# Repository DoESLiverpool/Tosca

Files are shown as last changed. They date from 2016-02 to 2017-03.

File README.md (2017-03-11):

# Code now at: https://bitbucket.org/goatchurch/bbhquad
# Instructions are at: https://github.com/DoESLiverpool/wiki/wiki/PolarGraph
# Issues still here for the moment

## Tosca

Machinekit-powered polargraph drawing robot.

As part of the [Phrased & Confused](http://www.phrasedandconfused.co.uk/) at [Liverpool Acoustic Festival](http://www.phrasedandconfused.co.uk/events/phrased-confused-at-liverpool-acoustic-festival-3) we're aiming to have a polargraph perform alongside a poet.

## Reference Links

 * [Machinekit](http://www.machinekit.io/) - the operating system to control the CNC motors.
 * [Gcode generation](https://github.com/DoESLiverpool/Tosca/blob/master/GcodeFiles.md)

## Name

Named after the mother of Knut, the famous *polar* bear from Berlin Zoo.

## Updates

System now does not use machinekit and is now able to run PWM-H-bridge servos and quadrature decodes directly from the board.

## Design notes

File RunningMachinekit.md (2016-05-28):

# Getting Machinekit Running

This assumes you've already got a Beaglebone with Machinekit installed, but can be expanded as we get more detail on installing things.  It also assumes you have a computer running Linux to connect it to.

## Starting Machinekit
1. Plug the Beaglebone into the laptop with a USB cable
1. Connect to the Beaglebone
  ```
  ssh -X machinekit@192.168.7.2 
  ```

  > If this doesn't work, then plug the Beaglebone onto the network with an Ethernet cable, and find its IP address via other means.  The Beaglebone only sets up the Ethernet on boot though, so you'll need to reboot it to fix that.

1. Connect through the network to the BB by running:  nmap -p22 192.168.0.255/24 and look for something that is open to get the ipnumber  (this should be fixed by https://github.com/DoESLiverpool/Tosca/issues/27 )
1. Log in machinekit@192.168.0.130 with the password machinekit over the network (or 192.168.7.2 if over the USB ssh over serial)
1. Run the machinekit software.  This will spawn a new window on your laptop, which is actually running on the Beaglebone and just using your laptop as a display.
  ```
  cd machinekit
  
  . scripts/rip-environment
  
  machinekit mk7_bbb_pcb.ini
  ```
1. Home the machine by using left right up down cursor keys to put the pen in the middle of the board with both strings at right angles to each other.  Click on "home all"
1. Type in the following Gcode command to set the current position to home.
  ```
  g92x0y0
  ```

## Drawing something

1. Load a Gcode file, with "File" -> "Open"
1. For example, go up one directory and load bighelloworld.ngc
1. [Optional] Manually jog to a starting point and set it as home with
  ```
  g92x0y0
  ```
1. Control the speed with manual Feed override and max velocity (for the "retracted" linking moves) 
1. Click the play icon.

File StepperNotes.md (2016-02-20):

# Stepper Version Notes

Notes on the version using the TLRN steppers.

For instructions on how to use the software to drive it, see [RunningMachinekit](RunningMachinekit.md) as the instructions are the same for both Polargraphs.

They have [BigEasyDriver boards](http://SchmalzHaus.com/BigEasyDriver) to run the steppers.  On the existing wiring, the colour coding is as follows:
 * White - direction
 * Blue - step
 * Green - sleep
 * Red - Vcc
 * Black - Ground

Pin mapping is in the .hal file.

If you ground pin P9-11, that disables the e-stop.

You can see the signals if you do machine -> show hal configuration

On the Beaglebone the pin-outs are as follows:
https://graycat.io/wp-content/uploads/2012/12/beaglebone_pinout.png

according to mk7_bbb_pcb.hal:
 * P9-11 - estop connect to Ground
 * P9-13 - limit switch connect to Ground 6 times during the homing cycle (before you can load an G-code)
 * P9-15 - probe-in (connect to ground to show it light up)
  
 * P9-29 - step (axis 0)
 * P9-31 - direction (axis 0)
 * P9-28 - direction (axis 1)
 * P9-30 - step (axis 1)

FIXME might be able to hack the HAL (/ini) to change speed, etc. for the homing and simplify that

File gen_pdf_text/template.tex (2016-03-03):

\documentclass[$if(fontsize)$$fontsize$,$endif$$if(handout)$handout,$endif$$if(beamer)$ignorenonframetext,$endif$$for(classoption)$$classoption$$sep$,$endfor$]{$documentclass$}
$if(theme)$
\usetheme{$theme$}
$endif$
$if(colortheme)$
\usecolortheme{$colortheme$}
$endif$
$if(fonttheme)$
\usefonttheme{$fonttheme$}
$endif$
\usepackage{amssymb,amsmath}
\usepackage{ifxetex,ifluatex}
\usepackage{fixltx2e} % provides \textsubscript
\ifxetex
  \usepackage{fontspec,xltxtra,xunicode}
  \defaultfontfeatures{Mapping=tex-text,Scale=MatchLowercase}
\else
  \ifluatex
    \usepackage{fontspec}
    \defaultfontfeatures{Mapping=tex-text,Scale=MatchLowercase}
  \else
    \usepackage[utf8]{inputenc}
  \fi
\fi
$if(natbib)$
\usepackage{natbib}
\bibliographystyle{plainnat}
$endif$
$if(biblatex)$
\usepackage{biblatex}
$if(biblio-files)$
\bibliography{$biblio-files$}
$endif$
$endif$
$if(listings)$
\usepackage{listings}
$endif$
$if(lhs)$
\lstnewenvironment{code}{\lstset{language=Haskell,basicstyle=\small\ttfamily}}{}
$endif$
$if(highlighting-macros)$
$highlighting-macros$
$endif$
$if(verbatim-in-note)$
\usepackage{fancyvrb}
$endif$
$if(tables)$
\usepackage{longtable}
% These lines are needed to make table captions work with longtable:
\makeatletter
\def\fnum@table{\tablename~\thetable}
\makeatother
$endif$
$if(url)$
\usepackage{url}
$endif$
$if(graphics)$
\usepackage{graphicx}
% Redefine \includegraphics so that, unless explicit options are
% given, the image width will not exceed the width of the page.
% Images get their normal width if they fit onto the page, but
% are scaled down if they would overflow the margins.
\makeatletter
\def\ScaleIfNeeded{%
  \ifdim\Gin@nat@width>\linewidth
    \linewidth
  \else
    \Gin@nat@width
  \fi
}
\makeatother
\let\Oldincludegraphics\includegraphics
\renewcommand{\includegraphics}[2][]{\Oldincludegraphics[width=\ScaleIfNeeded]{#2}}
$endif$

%gets rid of bottom navigation bars
\setbeamertemplate{footline}[frame number]{}

%gets rid of bottom navigation symbols
\setbeamertemplate{navigation symbols}{}

%gets rid of footer
%will override 'frame number' instruction above
%comment out to revert to previous/default definitions
\setbeamertemplate{footline}{}

% Comment these out if you don't want a slide with just the
% part/section/subsection/subsubsection title:
\AtBeginPart{
  \let\insertpartnumber\relax
  \let\partname\relax
  \frame{\partpage}
}
\AtBeginSection{
  \let\insertsectionnumber\relax
  \let\sectionname\relax
  \frame{\sectionpage}
}
\AtBeginSubsection{
  \let\insertsubsectionnumber\relax
  \let\subsectionname\relax
  \frame{\subsectionpage}
}

$if(strikeout)$
\usepackage[normalem]{ulem}
% avoid problems with \sout in headers with hyperref:
\pdfstringdefDisableCommands{\renewcommand{\sout}{}}
$endif$
\setlength{\parindent}{0pt}
\setlength{\parskip}{6pt plus 2pt minus 1pt}
\setlength{\emergencystretch}{3em}  % prevent overfull lines
$if(numbersections)$
$else$
\setcounter{secnumdepth}{0}
$endif$
$if(verbatim-in-note)$
\VerbatimFootnotes % allows verbatim text in footnotes
$endif$
$if(lang)$
\usepackage[$lang$]{babel}
$endif$
$for(header-includes)$
$header-includes$
$endfor$

$if(title)$
\title{$title$}
$endif$
$if(subtitle)$
\subtitle{$subtitle$}
$endif$
$if(author)$
\author{$for(author)$$author$$sep$ \and $endfor$}
$endif$
$if(date)$
\date{$date$}
$endif$

\begin{document}
$if(title)$
\frame{\titlepage}
$endif$

$for(include-before)$
$include-before$

$endfor$
$if(toc)$
\begin{frame}
\tableofcontents[hideallsubsections]
\end{frame}

$endif$
$body$

$if(natbib)$
$if(biblio-files)$
$if(biblio-title)$
$if(book-class)$
\renewcommand\bibname{$biblio-title$}
$else$
\renewcommand\refname{$biblio-title$}
$endif$
$endif$
\begin{frame}[allowframebreaks]{$biblio-title$}
\bibliography{$biblio-files$}
\end{frame}

$endif$
$endif$
$if(biblatex)$
\begin{frame}[allowframebreaks]{$biblio-title$}
\printbibliography[heading=none]
\end{frame}

$endif$
$for(include-after)$
$include-after$

$endfor$
\end{document}

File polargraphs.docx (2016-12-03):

Sandy Noble original polargraph

http://www.polargraph.co.uk – lots of stuff

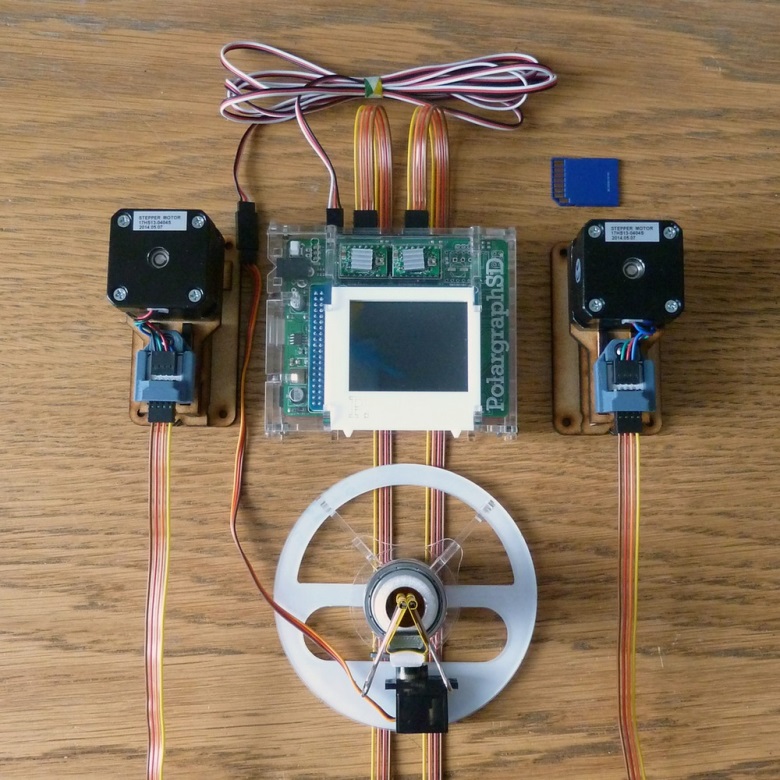
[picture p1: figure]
Image of PolargraphSD v2.0 - Complete, tested
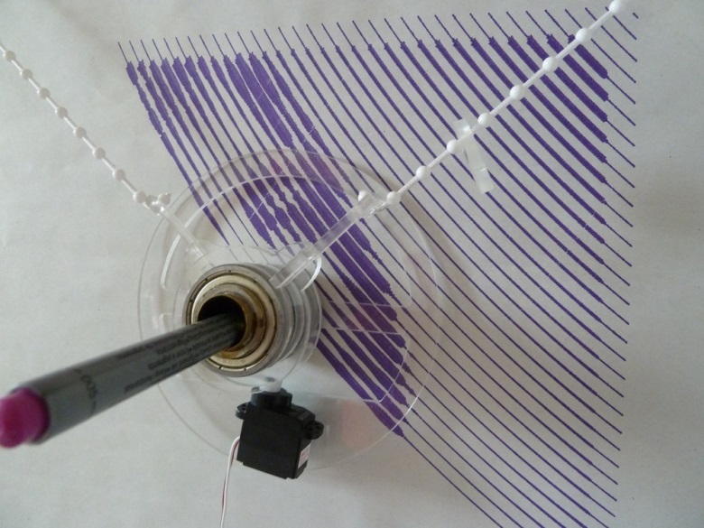
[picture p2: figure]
Image of PolargraphSD v2.0 - Complete, tested

http://www.instructables.com/id/Polargraph-Drawing-Machine/

https://github.com/euphy/polargraphcontroller/releases/tag/2016-03-29-10-23

Makelangelo

http://www.makelangelo.com/ Buy from https://www.marginallyclever.com/product/makelangelo-2-5-2/

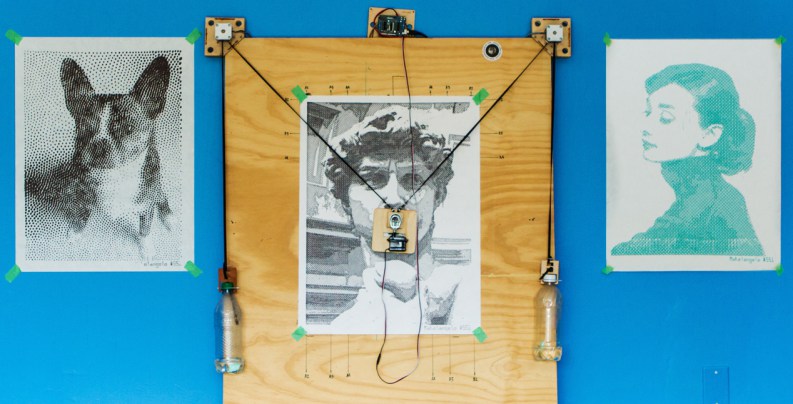
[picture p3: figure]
The Makelangelo 2.5

https://www.marginallyclever.com/product/makelangelo-software/

Mark Benson - Make Bournemouth

https://www.makebournemouth.com/?tag=polargraph

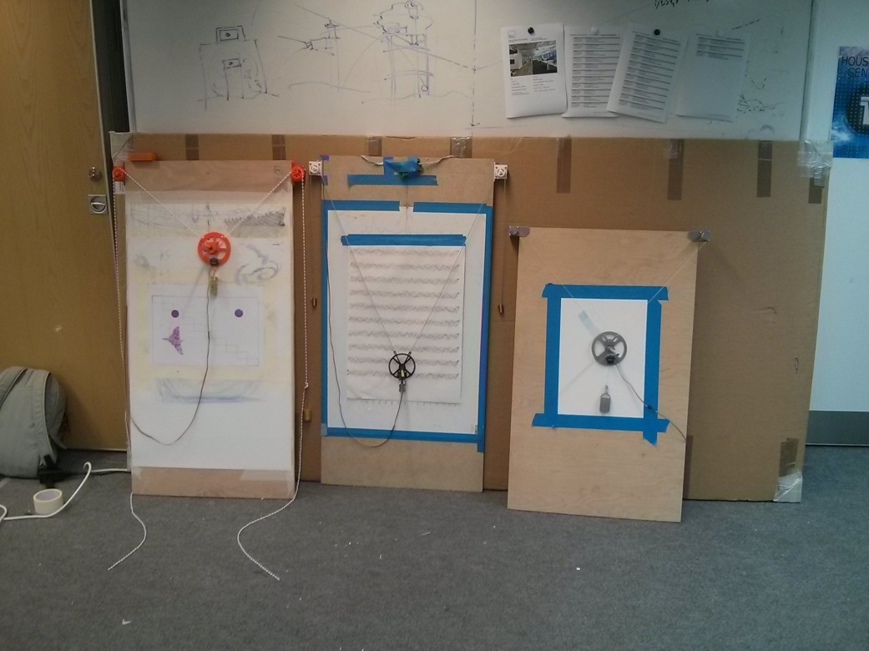
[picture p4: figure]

“The one on the left is running the Gocupi (https://github.com/brandonagr/gocupi) firmware and is being run with Pycupi (https://github.com/brianinnes/pycupi) a Python port/rewrite of the Gocupi ‘Go (https://golang.org/)‘ control software.

The other two are running the Polargraph.co.uk a1_server firmware variant modified to run on our (https://github.com/MarkJB/polargraph_server_a1) electronics (https://github.com/MarkJB/Eggbot-Spherebot-Polargraph-Controller).

The one in the middle is running with Pylargraph (https://github.com/MarkJB/pylargraph) which is a Python script to control the original firmware with the intention of plotting or graphing the result of a regular twitter search.

The other is running with the Polargraph.co.uk control software.

The various 3d printed parts are our own designs or modified versions of existing designs.

My own designs are available on github (https://github.com/MarkJB/Polargraph-printed-parts) and thingiverse (http://www.thingiverse.com/MarkBenson/collections/polargraph) but not everything is finished.”

https://github.com/MarkJB/Polargraph-printed-parts

http://www.thingiverse.com/MarkBenson/collections/v-plotter-polargraph-stuff

We’ve had a go at the gondola , which appears small and fragile – we think that the disc touching the drawing surface improved stability

Experimented with another disc further from the drawing surface to move the centre of gravity back

https://www.makebournemouth.com/?p=831 Pycupi v-plotter control software

Alex Weber – Der Kritzler– Designed for writing on windows!

https://tinkerlog.com/2011/09/02/der-kritzler/

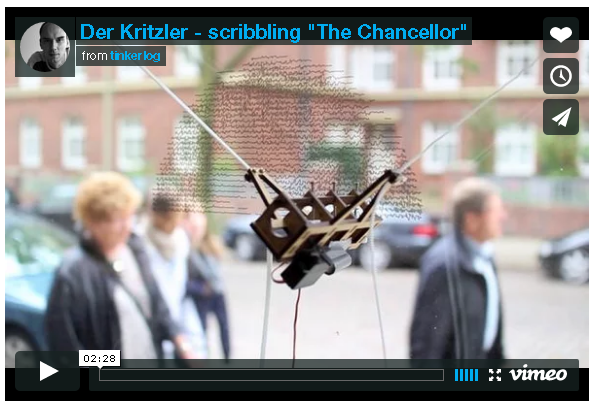
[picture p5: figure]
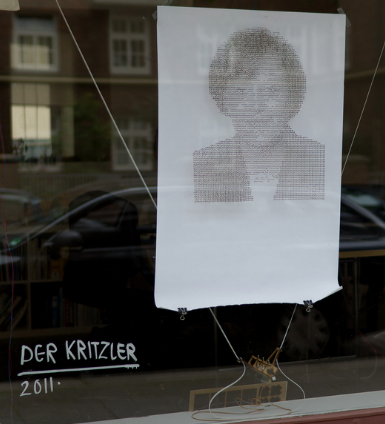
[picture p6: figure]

https://github.com/tinkerlog/Kritzler

Jacob Gertsch – LinuxCNC Bipod Plotter

https://www.youtube.com/user/ArduinoBeam

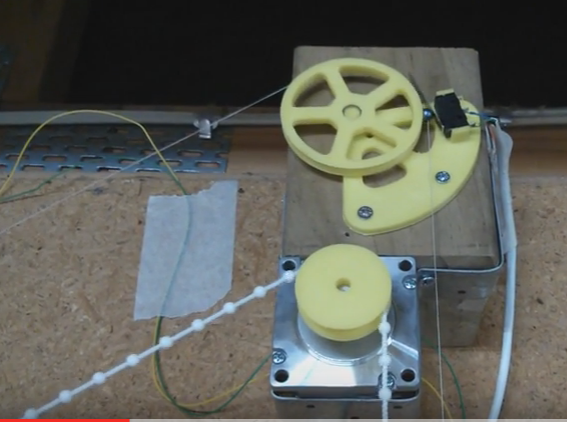
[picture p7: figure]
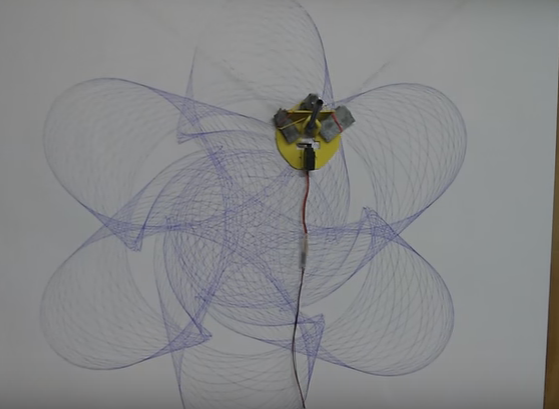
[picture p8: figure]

https://github.com/Chojins/LinuxCNC-Polargraph (mainly using Solidworks)

https://github.com/Chojins/Guilloche-Designer (spirograph-type designs)

Jakob Flierl - Koppi’s Toy (uses a toothed belt)

http://wiki.linuxcnc.org/cgi-bin/wiki.pl?Koppi%27s_Toy

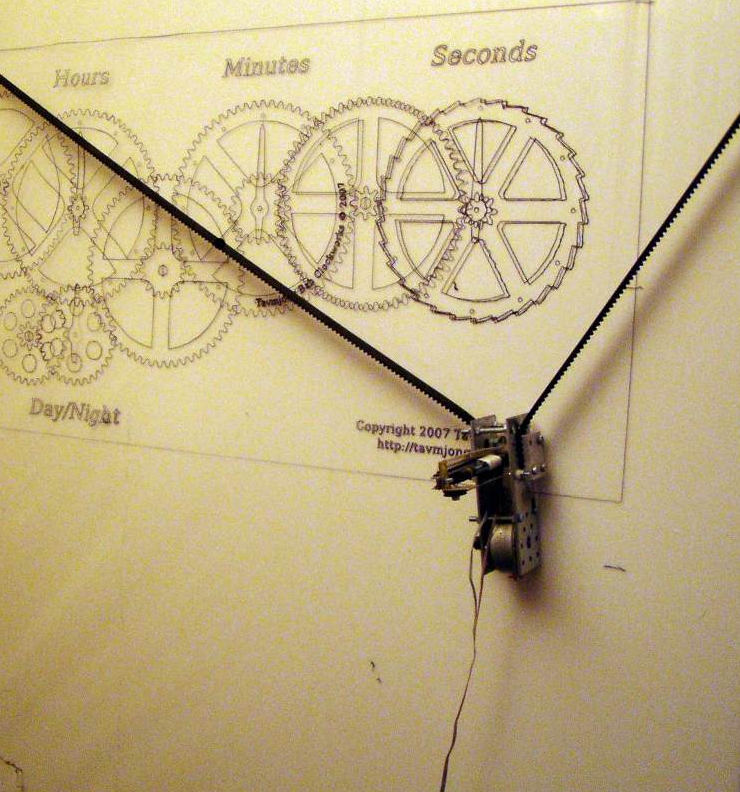
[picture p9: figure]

Matt Venn

http://www.mattvenn.net/2011/09/19/polargraph-energy-monitoring/

http://www.mattvenn.net/2015/12/19/megadrawbz/

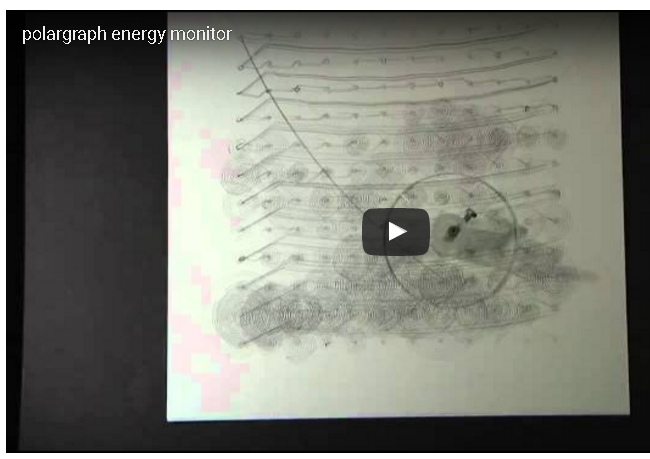
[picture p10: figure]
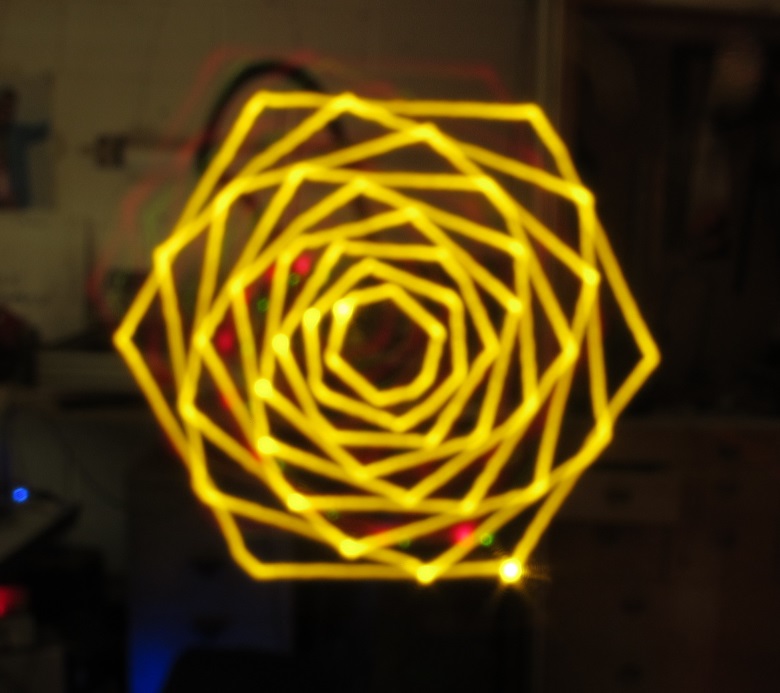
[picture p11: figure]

Brandon Dunson / Brandon Green - Gocupi Raspberry pi polargraph

https://github.com/brandonagr/gocupi

https://www.kickstarter.com/projects/1412673920/gocupi-turns-your-raspberry-pi-into-a-portable-pol

http://www.geeky-gadgets.com/transform-your-raspberry-pi-into-a-portable-polargraph-with-gocupi-05-08-2014/

https://blog.adafruit.com/2012/11/23/gocupi-go-raspberry-pi-polargraph-piday-raspberrypi-raspberry_pi/

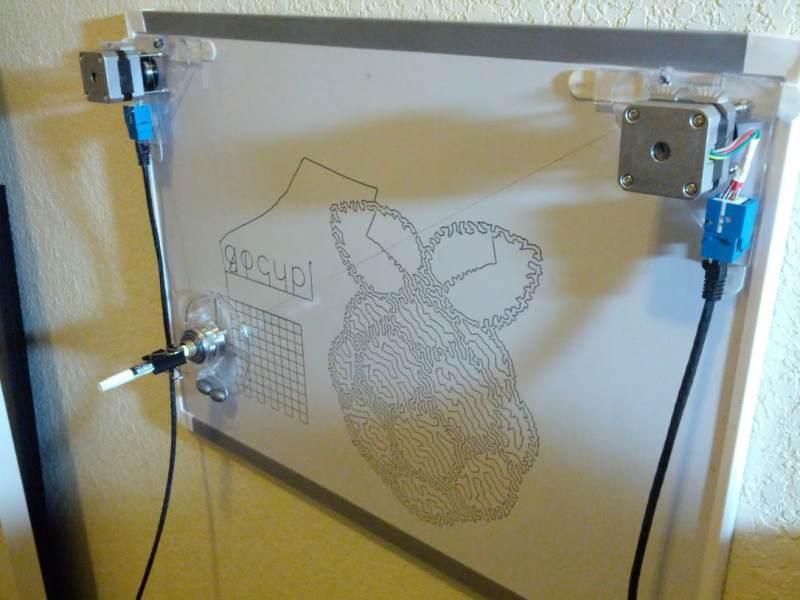
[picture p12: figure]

“This project is different from most other Polargraphs in that there is no step generation code on the arduino, everything is calculated in Go and then the arduino just receives a stream of step deltas that it stores in a memory buffer and then executes. Since all logic is written in Go running on the Pi it allows using more advanced interpolation models for smooth drawing, not needing to use fixed point or single precision floats for calculations, not needing to reflash the arduino often when making code changes, etc.”

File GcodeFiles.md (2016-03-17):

# Generating G-code files

Either fight it out with Inkscape, or use:
**http://doesliverpool.github.io/svgraph.html**

## Resizing for the playing area instructions
1. The width needs to be put into the machinekit/tosca.hal file (find it and change it on the BB)
1. Home point origin (where you start from) is width\*0.5 down from the top left pulley, and then across by width\*0.5
1. Edit twistcodewiki/cgipipe/xylimits

## Poetry instructions
1. Log on to BB, go into "twistcodewiki" directory and run the script "pytwister".  This makes a webserver that listens on port 9003.
1. SSH Log on to BB again in another window, but with -X setting: cd machinekit \n . scripts/rip-environment \n machinekit tosca.ini
1. This calls up the axisUI controlling the maching.  Move to home position, click [home], load /home/machinekit/poetrygcode.ngc
1. Go to http://doesliverpool.github.io/svgraph.html, fill in the IP number into the box, hit return and it goes green
1. Type your poetry into "svgizing letters here" box, click [svgizetext].  This will relay the poetry directly to the BB which will gcode it in space available
1. Click "reload" icon on axisUI and now click on run icon
1. Last 3 steps will happen from a POST command to http://192.168.7.2:9003/cgipipe/genpoetry.py?centre=no' where the POST data is the ascii text of the poem with '\n' linefeeds.
1. This enables the 3-click poem of "export from Csharp", "reload in axisUI", "run in axisUI"

## Toxteth map instructions
1. SSH log on to BB with -X setting. and boot up axisUI
1. The files to plot will be in ../performancegcodes/*.ngc numbered in order
1. I will help lay out the map and the icons onto the map (position and scaling) using svgraph.html technology on Friday morning

## Basic Instructions

1. Works best in CHROME browser.
1. Drag and drop your SVG file onto the screen **FIRST**.  This sets the scale.
1. (Alternatively to go from text, click on [svgize text] to make file from text box)
1. Use middle mouse scrollwheel to ZOOM on cursor.  There is no drag view!
1. Click on [MKstats] button to get the background drawing shape
1. Use Left Mouse Button to drag SVG data against the view, or Ctrl-Left Mouse to spin the shape (these features were designed for nesting)
1. Click [Save G-code] button to download fresh and thinned G-code, which you will then have to copy to the Beaglebone using scp

## Connected instructions

It's possible to get the G-code file to upload directly to the BB.

1. Log on to BB, go into "twistcodewiki" directory and run the script "pytwister".  This makes a webserver that listens on port 9003.
1. On the "svgraph.html" webpage, fill in the IPnumber for the BB and hit return.  If it works, this box will go green.  
1. The [MKstats] button will read the dimensions and status of the BB (in particular if it's running the Machinekit/Axis X-window application.
1. The [Send G-code] button will automatically upload and save g-code to a file called "/home/machinekit/gcodetwisted.ngc"
1. If the tickbox to the right is set, then it will attempt to autorun the g-code when it is uploaded.   (In the unlikely event this works, it won't redraw the picture on the Machinekit/Axis X-window

The webserver thing running on BB that holds the scripts is at https://bitbucket.org/goatchurch/twistcodewiki
Someone could replace it with a simple flask framework or something

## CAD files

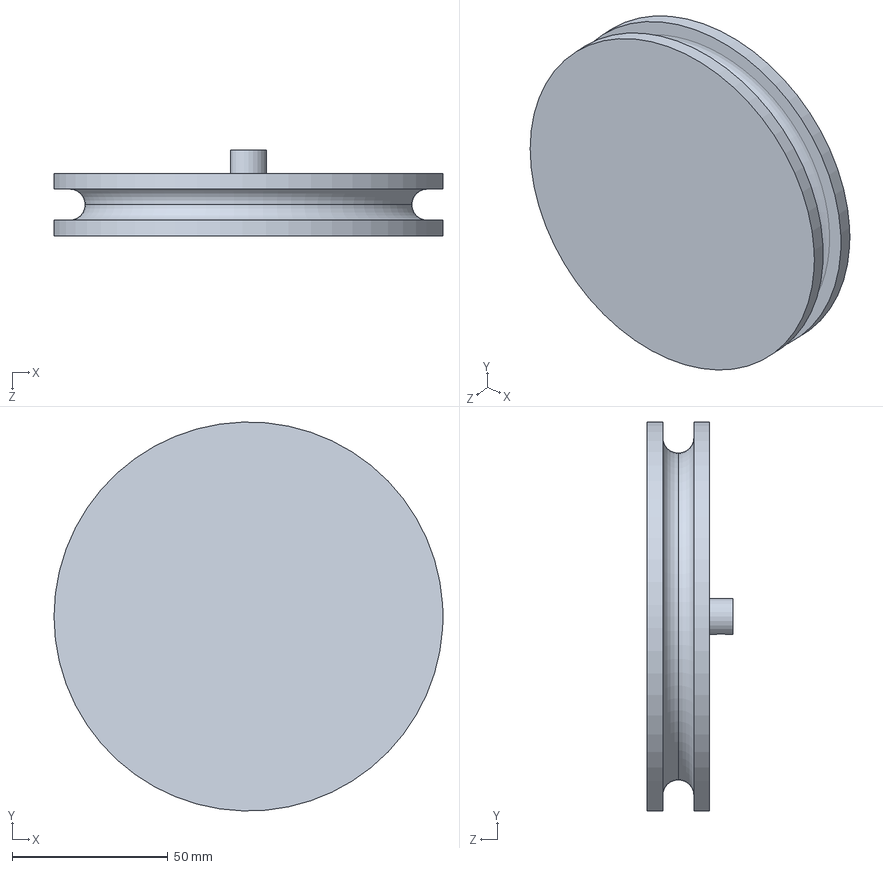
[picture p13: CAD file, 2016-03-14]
servo pully.SLDPRT
125.0 x 124.9 x 27.5 mm

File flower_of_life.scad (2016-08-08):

radius=60;

difference() {
    circle($fa=3,r=(3*radius)+3);
    circle($fa=3,r=(3*radius));
};

petal_pattern();
rotate([0,0,60])
        petal_pattern();
rotate([0,0,120])
        petal_pattern();

module petal_pattern(){

    for (i = [-3:1:2]) {
        petal(0, i);
    };
    for (i = [-2.5:1:1.5]) {
        petal(1, i);
    };
    for (i = [-2:1:1]) {
        petal(2, i);
    };
    for (i = [-1.5:1:0.5]) {
        petal(3, i);
        };
    for (i = [-2.5:1:1.5]) {
        petal(-1, i);
    };
    for (i = [-2:1:1]) {
        petal(-2, i);
    };
    for (i = [-1.5:1:0.5]) {
        petal(-3, i);
    };
};
module petal(petal_x_offset=0, petal_y_offset=0){   

        //echo([petal_y_offset]);
        
        translate([petal_x_offset*(radius/2)*sqrt(3), petal_y_offset*radius, 0])
        intersection() {
                translate([(radius/2)*sqrt(3), radius/2, 0])
                    circle($fa=5,r=radius);
                translate([-(radius/2)*sqrt(3), radius/2, 0])
                circle($fa=5,r=radius);
        }
};

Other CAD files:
servo pully.STL

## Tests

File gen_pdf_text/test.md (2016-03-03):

Lorem ipsum dolor sit amet, consectetur adipiscing elit.

Donec a diam lectus. Sed sit amet ipsum mauris.

Maecenas congue ligula ac quam viverra nec consectetur ante hendrerit. Donec et mollis dolor.

Praesent et diam eget libero egestas mattis sit amet vitae augue. Nam tincidunt congue enim, ut porta lorem lacinia consectetur. Donec ut libero sed arcu vehicula ultricies a non tortor.

Lorem ipsum dolor sit amet, consectetur adipiscing elit. Aenean ut gravida lorem. Ut turpis felis, pulvinar a semper sed, adipiscing id dolor.

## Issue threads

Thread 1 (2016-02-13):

Get machinekit running with stepper motors

amcewen, 2016-02-13:
Using @goatchurchprime's spare Beaglebone with Machinekit on it, hook it up to @DefProc's TLRN stepper motors and get it moving around with gcode.

DefProc, 2016-02-13:
Sounds cool, there's some NEMA23s in my box in the workshop, or some 17s in
the flight case in new dinky stores. They should both have spools attached,
but the mounts for the 17s are a bit better.
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

amcewen, 2016-02-13:
There's only one stepper in the flight case

amcewen, 2016-02-13:
But that's because we'd already borrowed two from it to try hooking up to machinekit :-D

DefProc, 2016-02-13:
:O
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

goatchurchprime, 2016-02-22:
Now runs reliably with manual homing and gcode

Closed 2016-02-22.

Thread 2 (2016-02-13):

Get machinekit running with the servo motors

amcewen, 2016-02-13:
We'll need to get the servo motors and drivers, and then another Beaglebone with Machinekit on it, wired up and moving around with gcode

amcewen, 2016-03-21:
Done.

Closed 2016-03-21.

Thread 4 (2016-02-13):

Find out how quickly we can draw with the servo motors

amcewen, 2016-02-13:
Can we get the servo motor version to write text quickly enough to "accompany" a poet?

@goatchurchprime was thinking it'd be cool to have it draw letters at random for key words from the poem being performed, and then time it right to have the last letter of the word drawn to coincide with the word being spoken in the performance.

We need to see if we can get it working quickly enough to do that :-)

amcewen, 2016-03-01:
We're going to be drawing simple pictograms rather than the text, so speed shouldn't be such an issue.  Would still be good to tune the speeds though to try to get it running quickly (so leaving this as a stretch goal...)

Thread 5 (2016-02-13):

Build limit switches for the spools

amcewen, 2016-02-13:
Machinekit expects to have limit switches so it can home properly.  We need to work out a way to find out when the spool has hit the end.

amcewen, 2016-02-20:
https://github.com/machinekit/machinekit-docs/blob/master/src/config/ini_homing.asciidoc is the Machinekit documentation for how homing works.  It looks like it will always home one axis at a time - you can set the order that it homes the axes or define that you don't care for certain sets of axes, but I couldn't see a way to get them to home at the same time.

goatchurchprime, 2016-03-01:
We can't pull the gondola off the playing area and all the way up to the pulleys, so the only way this will work is by having some markers attached to the strings that are at a known location which can be detected when in range (eg a little magnetic grain and a hall sensor) and we put them at a place where the get triggered when the gondola is at the top of the board, but not pulled off.  As long as the system always turns on with the gondola below these positions, then the homing cycle will work and not run off the edge.

DefProc, 2016-03-01:
Would a microswitch at the bottom of the gondola work?

Assuming a level base, it would let you drop both motors till the switch
operates, then pull both a bit up and lower one till the switch operates to
know overall position.
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

amcewen, 2016-03-02:
I think the big stumbling block (unless I'm misreading the Machinekit documentation) is how you get it to run a homing cycle that's anything more advanced than "run an axis until it triggers a limit switch"

goatchurchprime, 2016-03-02:
It's basically all about getting it to do a little dance on the motors and switches that ends with it being in a known position.

I reckon a more advanced homing cycle is possible to code through the Python interface where it runs combination movements on the axes (eg pull both in or both out), and spots trips on the limit switches.  Then it can click the "now it is homed" feature [c.home(0); c.home(1)] which just declares it done.

http://linuxcnc.org/docs/2.6/html/common/python-interface.html

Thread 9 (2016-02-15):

Find someone who's controlled a Polargraph with Machinekit

amcewen, 2016-02-15:
There are lots of Polargraphs around so it's quite possible someone has already worked out how to drive it from Machinekit.

Although wiring up the steppers is done, we still need to work out the code to map the geometry from X/Y to polar coords, and it'll be easier to reuse someone else's work.

So if anyone finds a link to a Machinekit Polargraph, or similar info, post it in as a comment.

jackie1050, 2016-02-15:
Not machinekit, but possibly useful code at polargraph.co.uk/sourcecode

goatchurchprime, 2016-02-17:
The code is here:
    https://github.com/euphy/polargraphcontroller/blob/2016-01-26-23-24/Machine.pde#L310

Turns out the conversion functions are pretty trivial.

If top left is (0,0) and top right is (width,0) and string is at (x,y) (where y<0) then
stringleft = ConstL + dist(x,y)
stringright = ConstR + dist(width-x, y)

Conversion back is a bit harder.

x^2 + y^2 = sl^2
(x-width)^2 + y^2 = sr^2
subtracting:
2.width.x + width^2 = sl^2 - sr^2
x = (sl^2 - sr^2)/(2.width)
y = sqrt(sl^2 - x^2)

These should be coded into a new version of the kinematics file as xytojoints() and jointstoxy()

https://bitbucket.org/goatchurch/maghullmachinecalibrations/src/adc5f2a6409a12d9d36265310b3fca2b518b494f/mk6skins.c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

This new file needs to be referenced in the INI file and for it to be compiled.

It ought to be possible trim down all the parameters (except for width) and set the values in the INI file to control the gearing and the home stops.  You can set the width through the HAL configuration.  This means that everything can be configured in the field.

The INI file will also set limits on the acceleration and max speed (lower acceleration, and high speeds are okay here), and it will compensate for going round corners.

goatchurchprime, 2016-02-22:
Code above has been put into mk7skins.c and committed.  Appears to work.
This software issue with machinekit appears solved and it's now hardware engineering from here on.

Closed 2016-02-22.

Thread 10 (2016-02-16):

Gondola for chalk spray?

jackie1050, 2016-02-16:
Would be good for outside of buildings

huffeec, 2016-02-17:
I like this. Have been thinking about how we can make a print head that moves quickly. If we went for a chalk/paintjet head it wouldn't have to be in contact with a potentially bumpy wall.

jackie1050, 2016-02-18:
Indoors could use black paper and uv light

jamieisboss, 2016-02-27:
I have some chalk pens, I'll try to remember to bring them if you want to try them out. They kind of drip feed so wouldn't work at 90 degrees to the glass for long, but 45 degrees should be alright. A couple of them fluoresce under uv so if that's what you're going for they could be a good choice? You won't need a black background if you have a good uv source.,you do have to be careful about reflection of the uv source when the glass is bare.

Stage e40 bulbs work a treat but I'm pretty sure your eyes melt if you look at them when they're on. I can ask a proper lighting guy if it'll help, all qualified and whatnot

For grip, maybe an air pump to create suction between the gondola and glass when drawing? Relay it on and off for speed or precision, mitigate the noise by putting it somewhere else and using a reasonably long tube?

jackie1050, 2016-02-27:
I've bought some uv pens already - going to try them out today, but pro

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

jackie1050, 2016-02-27:
I've bought some chalk pens now, but probably worth testing yours too. Interesting to know you don't need a black background - don't want to do anything dangerous though.

amcewen, 2017-06-12:
I have a couple of half-full spray chalk cans, [courtesy of @andatwhatcost](https://twitter.com/andatwhatcost/status/873217858360291328)... :-)

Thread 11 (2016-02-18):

Capacitive touch through a window to control it

amcewen, 2016-02-18:
For one put inside a window, it'd be interesting to make it more interactive - maybe use capacitive touch pads on the inside of the window to let people control it, without needing anything on the outside of the glass...

amcewen, 2016-03-09:
Now that we're running Knut as a poetry-battle, we won't need control-through-a-window.  Still, this would be a great thing to do sometime in the future (so moving milestone accordingly :-)

jamieisboss, 2016-03-18:
Was going to suggest for the glass, not sure how a poetry battle works, but could be behind the board so long as you remember where it is.

Cooler; under a table, if the tabletop wasnt too thick you wouldnt have to touch it just practise and it'd look very cool magically controlling the gondola just waving your hand in the air.

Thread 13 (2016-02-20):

Design and build two sets of "corner pulleys"

amcewen, 2016-02-20:
The motors and spools sit on the floor and the thread then loops over some "pulleys" (they'll likely just be eyebolts) in the top corners of the drawing area.

@DefProc used eyebolts on a laser-cut wedge for the TLRN to good effect, so we should build something similar to hold the two threads for the polargraphs.

amcewen, 2016-02-20:
A pack of 10 M6 eyebolts http://www.ebay.co.uk/itm/160870170069 has been ordered, should be arriving on Tues 23rd.

DefProc, 2016-02-21:
Ah. I have some spare
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

goatchurchprime, 2016-02-22:
Might need these to be real pulleys that introduce less friction into the system. There is a huge difference in force pulling in and letting out, and it's the letting out that's critical to the speed.  The string needs to run easily when the gondola is put into falling mode.

amcewen, 2016-02-24:
The eyelets have arrived and are in the Tosca storage box.

DefProc, 2016-02-24:
The braided fishing line is UHDPE, so it should provide it's own bearing surface, so it's unlikely to significantly reduce the amount of friction in the system (although there is some wear, so for ultimate longevity, pulleys are *technically* better).

What's the requirements for mounting the top brackets? Self-adhesive pads onto a painted/glass surface? Screws and rawl-plugs into a drilled hole in blockwork?

How many strings do you need to control? The current implementation seems to have two per motor. Is that just because the motors are mounted to double pulleys? Will you switch to a single line? *(The 0.45mm line **is** strong enough)*

amcewen, 2016-02-27:
The two strings help with the stability of the gondola, so we're sticking with two string option.

In discussions today we reckoned that the current TLRV versions are working well, and we won't know any more about how they need to be attached until we've had the site visit (issue #19), but then might just need to get a copy of the files and cut a second set.

DefProc, 2016-02-27:
Ok, they are designed for a single centre screw mount, but could be
adhesively mounted is the base surface is good enough
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

amcewen, 2016-03-13:
The Knut polargraph will be mounted on the window, so we should be able to reuse the existing mounts with some command strip (I've bought some, it's currently on my desk though I'll stick it in the Tosca box in the workshop)

For the main Tosca polargraph, @epsaul, presumably we can just add some eyelets to the top corners of the drawing board?

amcewen, 2016-03-15:
We're going to use the eyelets chased into the drawing board, so this is now sorted!

Closed 2016-03-15.

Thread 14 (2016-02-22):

G-code unit scaling

helicalbytes, 2016-02-22:
I have some text from SVG fonts ready to  convert to g-code for testing. Just want to check the scaling. That is, how many g-code units equal one physical unit (e.g. cm) on the drawing surface?

goatchurchprime, 2016-02-22:
The scale is set in mm.  One G-code unit for 1mm.

On the current whiteboard setup we can safely go X-200, to X200 and Y-200 to Y200

Z is ignored, but takes time, so go up and down in it by 1mm.  May be used for the pen servo later.

See Issue#15 about corner rounding and possibility of non-outline letters.  (More like hand-writing type letters).

For emphasis we'd do more interesting shaded letters where areas are hatched or painted in.

helicalbytes, 2016-02-23:
Thanks for info. Regarding single line (as distinct from outline) fonts, I did have a look for some of these a few days ago. I found a few that are used for engraving and other similar applications, but I wasn't sure if there are any that are widely known and used?

Closed 2016-02-24.

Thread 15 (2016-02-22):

Establish a protocol for working out speeds and corner rounding parameters

goatchurchprime, 2016-02-22:
When you actually play a toolpath you find that it rounds off the corners to keep up the speed:

The parameters for controlling this are given in:
http://machinekit-docs.readthedocs.org/en/latest/src/common/User_Concepts/

In particular G64P0.5 means we will follow the path to a tolerance of 0.5mm and keep up the speed as much as possible as we go along.

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

We'll need a test example (G-code file) to run against that we use to tune the cornering rate and feedrate in order to get the fastest plot for the minimal degradation in cornering capability.

Maybe it will require 2 files with 2 different fonts in them that to show off the difference in speed if the letters are rounded vs with all sorts of corners and serifs.

Also might want a font that isn't outlines, to make the writing of letters twice as fast

goatchurchprime, 2016-02-27:
The setup protocol also needed to establish the Z-height for pushing the pen in and out.  There's a home button on the base jeenode that sets to the middle of the travel range.

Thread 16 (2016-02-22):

Design a gondola with 4 wires and a weight

goatchurchprime, 2016-02-22:
I have bodged this with gaffer tape and a pair of metal pliers, and strung up the extra strings to keep the pen level.  There is a lot less jerkiness.   This has the potential to make something more rigid and not dependent on the friction of the pen tip.

There's still a free movement of rotation that allows oscillation that I'd like to get rid of -- even though it might be less important when the rotation is about the axis of the pen.  It still would make it difficult to run with more complex structures with 2 pens in them.

Maybe the CofG needs to be lowered down an hung in such a way that it is lifted by the strings if it is anything other than level.

goatchurchprime, 2016-03-01:
We need to get the hanging eyelets closer together on the line perpendicular to the pairs of strings.  At the moment the pen angle to the board changes quite a bit from the bottom to the top.

Needs hooks on the front strings of the gondola to allow for fine adjustment of string length to get the pen level.

Don't forget a place for the Jeenode and 4xAA cell battery pack.  This has run for at least 24 hours without stopping so there's no problem with the power supply.

amcewen, 2016-03-01:
I think it'd be useful for the pen to be mounted angled slightly downwards rather than perfectly horizontal - that'll help ink flow to the tip.

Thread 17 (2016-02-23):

G-code from text -- for testing

helicalbytes, 2016-02-23:
Attached are some g-code files rendered from SVG glyphs for testing.

I'm not familiar with the g-code format so what I've done I'm sure isn't best practice! However the output does seem to render OK in Camotics, which is an open source CAM simulator (screenshots below). Please let me know about any mistakes I've made.

In particular, for 'move' operations I've used the following 'pattern':

G0 X-121.40 Y-36.84 Z1               // z = 1, fast move (G0) to start of new path section
G1 X-121.40 Y-36.84 Z0 F100     // z = 0, with feed = 100
G1 X-124.91 Y-36.67 F100           // move to end of first line

There are three files at different sizes in the zip, each showing the word 'tosca'. The origin for these is approximately in the center of the text.

tosca-300.gcode.txt : total width approx. 300mm (g-code units)
tosca-150.gcode.txt : approx. 150mm wide
tosca-75.gcode.txt: approx. 75mm wide

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
[tosca.gcode.zip](https://github.com/DoESLiverpool/Tosca/files/142614/tosca.gcode.zip)

amcewen, 2016-02-26:
http://www.cambam.co.uk/forum/index.php?topic=1557.0 has a selection of single-stroke fonts, and if you install the latest version of Inkscape then you'll also get the Hershey text extension (in the Eggbot extensions), but that seems not to be a simple font file - it's at https://github.com/evil-mad/EggBot/blob/master/inkscape_driver/hersheydata.py (which has links to the source it's derived from in the comments) in case that's of use

helicalbytes, 2016-02-26:
Thanks for those. Have put a couple of cambam ones through the font software I use to convert them to SVG and that works fine. They render OK using my code too. Will put some g-code generated from these over next couple of days.

amcewen, 2016-03-15:
Now we've got the SVGizer for text, I think any remaining text work will be covered under issue #23

Closed 2016-03-15.

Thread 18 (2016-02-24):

Pen up pen down system from Z-axis control

goatchurchprime, 2016-02-24:
In original design this is done using a servo that operates a lever to push itself (and the pen) out of contact with the surface.

Using the z-axis to control the pen position allows for pressure changes and quick response during travel (eg to make dotted lines).  This is going to be more dynamic than using tool changes or coolant on/off settings as a proxy.

The home value would be where the pen is only just in contact with the surface.  There should be travel on either side so that we can exert variable forces.

It's probably going to work wirelessly using a Jeenode pairing, with one Jeenode on the gondola receiving a Z-value and controlling a mini servo motor accordingly.  The transmitting Jeenode would read from the BeagleBone.  We can just use it to read two pins (step and direction), which can be decoded in an arduino with step connected to one of the IRQ pins that increments or decrements a register up through a distance of 1mm (in machinekit world).

This BB INI file can have all the settings for number of steps in a mm and the speed of acceleration (high as there's no intertia).  The arduino initially would use a cable to the gondola to control the servo directly.

We therefore should begin by wiring up an arduino and make a sketch to receive step and direction (pins P9.26, P9.24 according to the HAL file) to control a servo on the table right now.

DefProc, 2016-02-24:
I have some jeenodes, and lipo batterys that would be suitable.

goatchurchprime, 2016-02-27:
This is now working with https://github.com/DoESLiverpool/Tosca/blob/master/jeenodezdecoder/jeenodezdecoder.ino and https://github.com/DoESLiverpool/Tosca/blob/master/jeenodepenactuator/jeenodepenactuator.ino which have been gaffertaped to the gondola with a 5V 4xAA battery pack (note 7.2 volts melts the servo).

There's a home button on the zdecoder that transmits a home signal to the gondola.  It's not perfect, and there's some configuration relating z values to pen positions.  The RF code needs to send ACKs to make it more reliable.

Closed 2016-02-27.

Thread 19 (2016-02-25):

Have a site visit

amcewen, 2016-02-25:
We need to work out how we can rig it, etc. so visiting the venue would be really handy :-)

JennyHarris, 2016-02-26:
Shall I put you in contact with Richard the venue manager?

amcewen, 2016-02-26:
Ooh, if you could, that would be great!

amcewen, 2016-03-01:
Site visit arranged for 1pm on Weds 2nd March.

amcewen, 2016-03-03:
Visit done!

There are some photos I took at https://www.flickr.com/photos/amcewen/albums/72157664813872800

The window version shouldn't be too tricky: we can easily run power to one of the window ledges, and put everything on there.  The windows are over 10ft wide and more than 7ft high, so there's a nice big area to draw on.

For the main performance area - the screen can't easily be moved (and Lizzie has some photos she'd like to project onto it anyway).  We think the best approach is going to be to hang the drawing area to the left of the screen (when looking at it from the audience, like in https://www.flickr.com/photos/amcewen/24811058904/in/album-72157664813872800/).  There are hefty scaffold poles mounted vertically (as can be seen in https://www.flickr.com/photos/amcewen/25415458676/in/album-72157664813872800/ although those are to the right of the screen) which are 48mm diameter.  The ones to the left are 10 feet apart, so we could fairly easily hang a full size sheet of plywood between them.  We need to avoid the fire exit, but that's unlikely to be a problem.  The venue have the right kit to get access to them to do the hanging.  It's probably best to build it as a self-contained unit just needing power, as it'll be trickier (although not impossible) to have things on the floor below it (particularly on the left side, as that'll be off the edge of the stage and near the fire exit)

There's WiFi available (and should be decent, as they use it to livestream things).

They also have flexibility with how it could be lit, although we weren't sure what we want beyond maybe having a spotlight pointed at it :-)

amcewen, 2016-03-03:
Issues #3, #7, #13, and #33 updated with details learnt after the visit, so I think we can close this issue now.

Closed 2016-03-03.

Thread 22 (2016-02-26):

Get some pens that can draw on windows

amcewen, 2016-02-26:
The stepper-based version is going to draw on the inside of a window (so passers-by can see it - and maybe even interact with it).  So we need to get some pens that can draw on the window (and that can be cleaned off afterwards too :-)

jackie1050, 2016-02-26:
'll try to get some scraps of black foamcore or correx to try them out on too

amcewen, 2016-02-26:
There is a spare glass bed for the RepRap that I'm sure we could try, and I guess there'll be plenty of glass bottles in the recycling for initial "does this write on glass, and can we clean it off?" testing :-)

Plus some windows in Dinky and the main office that we can try rigging it up onto...

jackie1050, 2016-02-27:
I have bought some pens. Currently at DoES so hopefully will be able to try them out later.

amcewen, 2016-02-27:
Cool.  The RepRap glass is in the 3d printing supplies cupboard under the printers, if you want that to try out.

I've got some stuff to do, but should be in DoES around 3ish

jackie1050, 2016-02-27:
Chalk markers do write on glass

Closed 2016-02-27.

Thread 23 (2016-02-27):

Decide what the window polargraph is going to draw

amcewen, 2016-02-27:
The stepper polargraph is (hopefully) going to be sat in one of the windows of the Music Room, so passers-by can see it.

It's probably going to draw poems, but we need to work out how that works.

There's been discussion so far about maybe writing some Markov-chain software, or something similar, that auto-generates text given some source examples.

That fits nicely with Adrian Henri's work like [the New, Fast, Automatic Daffodils](http://www.adrianhenri.com/writer-poems-automaticdaffodils.html) where he mashed up Wordsworth and car adverts.

If we could find a suitable source text for advertising copy, and similar for Adrian Henri and Wordsworth, then we could autogenerate modern equivalents...

amcewen, 2016-02-27:
https://blog.arduino.cc/2016/02/17/macchina-poetica/ and http://www.bbc.co.uk/rd/blog/2016/02/irfs-weeknotes-number-213 might also give some ideas about auto-generated text.  And I built (well, did some simple copying ;-) a "Horse Tweets" twitter markov bot called [@policyomatic](https://twitter.com/policyomatic).  That takes a load of manufacturing policy documents as its source text, and then spits out auto-generated samples.  The original twitter-bot script that I stole is https://gist.github.com/koffeinfrei/a0ebc5c9295c067fe5ff

epsaul, 2016-03-08:
Link to the poetry algorithm http://www.aaai.org/ocs/index.php/HCOMP/HCOMP14/paper/viewFile/9049/8986

helicalbytes, 2016-03-15:
[hello-tosca-0.25.gcode.txt](https://github.com/DoESLiverpool/Tosca/files/174593/hello-tosca-0.25.gcode.txt)

helicalbytes, 2016-03-15:
[hello-tosca-0.05-gcode.txt](https://github.com/DoESLiverpool/Tosca/files/174626/hello-tosca-0.05-gcode.txt)

jackie1050, 2016-04-30:
Poems created and performed at the event - joint first prize won

Closed 2016-04-30.

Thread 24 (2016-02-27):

Z-axis movement is unreliable [was "Recode the Jeenode sending to use ACK"]

goatchurchprime, 2016-02-27:
The z-axis is sometimes slow to respond and sometimes (@amcewen thinks) misses a whole raise or lower sequence (seen with @goatchurchprime's checkerboard test gcode).

We need to find a way to fix that.

Below is the original suggestion of something to try, but check below for other suggestions...

Continuation of issue 18:  https://github.com/DoESLiverpool/Tosca/issues/18

Current code in https://github.com/DoESLiverpool/Tosca/blob/master/jeenodezdecoder/jeenodezdecoder.ino uses:

        rf12_sendStart(1, payload, payloadCount*sizeof(int));
        rf12_sendWait(RF12_NORMAL_SENDWAIT); // wait for send completion

Some packets get missed which means the pen doesn't move in time (and gets set at the next heartbeat).

A solution would be to require ACKs to make sure the packets are getting through (and so it can retry multiple times if it doesn't).  This will improve the relability.
    http://jeelabs.org/2011/01/12/relaying-rf12-packets/

amcewen, 2016-03-03:
I've marked issue #31 as a duplicate of this, and edited this one to show the problem that needs solving, rather than one of the possible solutions (now that we'd ended up with two issues trying to solve the same thing).

amcewen, 2016-03-03:
Personally I don't think that switching to IR over RF would be a good idea.  With RF we at least have *some* experience, whereas IR is switching to a whole new domain for all of us.  And when did anyone last have a phone with an IR port?  Or use the one that it had?  I think there's a reason that Bluetooth/Wifi/etc. won out over IrDA :-D

I've got a pair of XBee modules which might be more reliable than the RFM12 modules.  They're on @goatchurchprime's desk at present.  They're targetted at higher bandwidth than the RFM12 modules, if nothing else...

amcewen, 2016-03-15:
Moving to XBee seems to have improved matters considerably.

Closed 2016-03-15.

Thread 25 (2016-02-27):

Design and cut a Beaglebone PCB cape to break out the PRU driver pins and inputs

goatchurchprime, 2016-02-27:
Requires level shifters on the inputs and outputs to protect the BeagleBone and provide current to drive optocouplers in the drivers.  Also will have push connectors and/or screw terminals for the various pins grouped by axis.  Intends to be _exactly_ the same board that gets used on the arcitype mill.

goatchurchprime, 2016-11-24:
done ages ago

Closed 2016-11-24.

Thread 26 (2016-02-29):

Locking pins on the motors when power switched off

goatchurchprime, 2016-02-29:
At the moment the whole thing slams to the ground when the power is cut.  This will happen with the servos as well as the steppers.  Need some way to park the motors so they don't do this.

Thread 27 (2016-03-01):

Sort out advanced OS matters on the BB

goatchurchprime, 2016-03-01:
1.  Need a way to obtain the IP number of the BB without needing to search for it on NMAP.  Adrian mentions some sort of MDNS technology.

2. Need a way to disconnect from the BB while leaving the terminal window and it's X-windows "axis" UI interface running, and then be able to reconnect to it and carry on.  Otherwise when running a long operation we're stuck with having to have a separate laptop connected at all times just to see the UI and do nothing else.

amcewen, 2016-03-01:
For (1), I've used "apt-get install libnss-mdns" on the Raspberry Pi.  That means you can then connect to it as hostname.local, so it'd be machinekit.local.  If that works then we should look at giving each polargraph its own hostname (tosca-stepper and tosca-servo?) so we can connect to them both (once we've got more than one...)

amcewen, 2016-03-01:
And for (2), I've not used it, but a quick google suggests that https://en.wikipedia.org/wiki/Xpra would do the trick

amcewen, 2016-03-06:
The mDNS stuff is already installed on the Beaglebone, so it was available as beaglebone.local.

I've updated the hostname (following the steps in https://sheldondwill.wordpress.com/2013/12/14/43/ - which is basically "edit /etc/hostname and /etc/hosts, then reboot") and set its hostname to tosca.

So now to ssh in you just need to do ```ssh machinekit@tosca.local```

We'll need to change the name on the other Beaglebone (to knut, for the stepper-motor version) once we've got two Beaglebones on the network :-)

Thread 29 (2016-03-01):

Buy the parts we need

amcewen, 2016-03-01:
There'll be a chunk of stuff that we need to buy for the two polargraphs.  As the performance isn't too far away, we need to get things ordered sooner rather than later.

Add things to this list (edit the issue) and we can get them ordered, and then check them off once they've arrived.  Links to where to get them from preferred (and saves @DoESsean asking you where to get them from :-)

Need buying before the performance:
 * [ ] More command strip

Ordered/arrived (checked off when they arrive):
 * [x] Eyelets
 * [x] Chalk markers
 * [x] Rolls of paper (https://www.jacksonsart.com/crescent-graffiti-manga-paper-white-paper-roll-40-inch-x-30-foot-150gsm and https://www.jacksonsart.com/fabriano-accademia-drawing-roll-90lb-200gsm-acid-free-1-5m-x-10m-4-5x33-feet)
 * [x] Command strip (leaves no residue adhesive pads to fix corner pulleys #13 to the window)
 * [x] Arduino FIO board x 2
 * [x] Servo
 * [x] Big Easy stepper driver
 * [ ] Emergency stop button x 2 (for issue #12)
 * [x] [Beaglebone green](http://www.mouser.co.uk/Search/ProductDetail.aspx?R=102010027virtualkey67130000virtualkey713-102010027) x 2
 * [x] Series 1 XBee module with whip antenna x 2 (http://uk.farnell.com/digi-international/xb24-awi-001/rf-module-txrx-xbee-wire-ant/dp/1337912)
 * [x] [8' x 4' sheet of MDF x 2](http://terrystimber.com/product/smooth-ply-wbp-ext/)     ( Watch out for the thickness you need  - 1" weighs too a lot, 1/2" is probably a good balance if it's strrong enough)  n.b. they also do 5' x 10' there if you were just going  for the biggest common size

amcewen, 2016-03-01:
@huffeec it'd be good to know what stuff we need for the servo motors pulleys so we can get that ordered.  @DefProc can no doubt advise on that too, given he bought stuff (and has design files, so bug him for them for issue #3 ;-) for the stepper pulleys, etc.

amcewen, 2016-03-01:
@goatchurchprime Where did you get the Beaglebone Greens from?  Is 2 going to be a good number to buy?

goatchurchprime, 2016-03-01:
Beaglebone greens got from here:  http://www.mouser.co.uk/Search/ProductDetail.aspx?R=102010027virtualkey67130000virtualkey713-102010027  £64 for 2 with vat.

2 puts it over the £50 limit for free shipping.  I think we got enough floating around that we don't need more spares.

If you're ordering from there, I'd like one of these big yellow OLED displays:
    http://www.mouser.co.uk/Search/ProductDetail.aspx?qs=8UoQy1KDZL7fwY%2fpFrKBgw%3d%3d

amcewen, 2016-03-03:
@DefProc Where did you get the command strip from that you used to mount the corner pulleys onto windows?

amcewen, 2016-03-09:
I've ordered two rolls of paper (wasn't sure if the wider one would bleed through at all) for us to use as a writing surface for the main performance and/or for use to draw things on afterwards when it's installed in DoES somewhere

amcewen, 2016-03-13:
@epsaul Do we know how we're going to hang the drawing board from the scaffolding poles?  Do we need to buy any clamps?  Cable?

amcewen, 2016-03-14:
Servo, new stepper driver board and XBee-based Arduino boards ordered.

jamieisboss, 2016-03-15:
I can reccomend http://www.scaffolding-direct.co.uk/ , you likely dont need actual scaffold pole (no qualified to say hat but you could always add support), aluminium would be much easier because the steel is just so heavy, they wil cut to size for you, have a whole range if clamps and fittings and the delivery is usually a lot but theyre based in bromborough and will allow collection if you call them.

Unfortunately can't make any promises, it'd be for a society thing and need to secure funds -  but i'll probably have a use for any pole and clamps you buy, and would be happy to buy them from you if you don't need them after this and they're not being altered dramatically and I get the funding together. Three caveats, but t's actually quite likely

JennyHarris, 2016-03-15:
How heavy is it?  Good quality ratchet straps may do the trick.  I've used these to hang big mdf panels from scaffolding before.

amcewen, 2016-03-15:
I don't think it'll be too heavy.  Discussing with @epsaul just now, he's going to source the wood and some thick enough cord/rope to use to fasten it up.

I've ordered the XBee and Beaglebone Green boards too.

jamieisboss, 2016-03-16:
the ply will be 40KG +- 15% for the type of wood and treatment google says 42KG for 2 sheets,  if you get 12mm (vive la revolution!) if you went for 3/4" (18mm) that'd make it 66kg for ply

Then if you're planning  to screw hat to some 3"x2" thats 1.4kg/m (im just googling), assuming you'd do a garden gate back with 20mm clearance so you coudnt see it from he front and i's all 2m for ease  and you ended up with PAR redwood, thats a 10Kg.

Adding in the scaffold if you use aluminium would be 2kg/m  (needed wolfram for that) you'd need about 16m if you add in the props, joining clamps and a base with wheels , getting up to 85Kg

If you use steel scaffold that's 4mm thick its 4.37Kg/m so 70kg for the scaffold, call it a round 120Kg for the lot without any functionality besides wheeling.

Just as a caution that if you've got to get that on and off the stage, and it'd be 3m tall by that point so wont go through a doorway, you probably want to think about the weight and moving it , plus if its at the phil you'll kill the stage finish unless you get the right castors

jamieisboss, 2016-03-16:
I realise none of that was helpful, so maybe if you made it so the middle folded, and the wheel base that was on one side could relocate to the other top corner and the bottom to its 90 degree so then you could strap it/clamp it at the bottom and wheel it out?

jamieisboss, 2016-03-16:
so 3 corners would be like this fitting

http://images.scaffolding-direct.co.uk/product-images/1000-1000/328-176d.jpg

then you have  short piece to join to a regular T whih has corners and castors, then they can come out of the bottom, go on the side and fold it in the midddle.

That makes more sense than the first way i described it. Unless he stage exit is big enough for you to just wheel it off and diassemble it but i dont remeber i being

jamieisboss, 2016-03-18:
Hope my calculations and googleings were of some use not just inane babbling,

I assume from the photos it went alright, can i ask what the weight was like in the end and how you managed it? As mentioned above, i have a similar scaffold project coming up so any experiential wisdom shared would be much appreciated

amcewen, 2016-03-21:
@jamieisboss In the end we hung it from their lighting rigging rather than the scaffolding poles, and it also rested on the floor as we decided that was safer than hanging all that weight from the frame of the board.

amcewen, 2016-03-21:
Any further items we need to buy are going to be best raised as individual issues as and when we encounter them now.

Closed 2016-03-21.

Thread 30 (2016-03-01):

Generate SVG for the main performance pictograms

amcewen, 2016-03-01:
For the main performance we're drawing a map (see issue #20) and then overlaying that with pictograms that tie into specific locations and parts of the performance.  So we need to design(/source) SVG files for each of those.

I'll update this issue as we get the list from Lizzie, but so far... (check them off when done, and leave a comment with the location of the checked in file):

 * [x] Mouse. It only needs to be an outline but something realistic rather than cartoonish
 * [x] Cat
 * [x] Pigeon
 * [x] Cloud
 * [x] Balloon
 * [x] Fish
 * [x] Tree
 * [x] Bat
 * [x] Dog

goatchurchprime, 2016-03-07:
We need these really soon so we can calibrate the time to draw them and their sizes.

Get any examples now which look kind of artistic as a stand in so we're not always drawing "Hello world"?

Arty examples to chase up that would look appropriate someone there could chase up:

1) One of Ed's astrolabe patterns (possibly simplified so it draws in finite time)
2) Ed's 3 piece suit cloth cutting pattern, or a dress pattern.
3) A DXF technical drawing of some of the component designs for the motor boxes, or JD's monitor case
4) A nice circuit diagram from kicad of the schematic or the tracks

amcewen, 2016-03-09:
I've pinged Lizzie to see how things are going and to get some more things-to-draw from her, but @epsaul will hopefully be able to provide an astrolabe pattern or similar.  There's still the map of Liverpool city centre (I've not generated one for Toxteth yet) to try out - that's checked into this repo in the Examples folder.

amcewen, 2016-03-13:
We've got the full list now.  Any help in sourcing these much appreciated - either drop SVG files into the Examples folder in the code section, provide a link in a comment, or email me a file :-)

And tick off any you source, so everyone can see what still needs finding.

jackie1050, 2016-03-15:
Will update at lunchtime

jackie1050, 2016-03-17:
Only pigeon, cloud, fish, and cat have been approved by Lizzie so far. I've sent the others to her to see if they're what she's after

jackie1050, 2016-03-17:
All now approved - need to test esp. for time taken and size

jackie1050, 2016-03-17:
Final list of pictures and locations

Child
Fish on Spekeland Grove
Tree on Fern Grove
Mouse on Mozart Street

Lover
Pigeon on the junction of Rodney Street and Mount Street
Cat on Rice Street outside the Cracke
Balloon on Percy Street

Death
Bat on the junction of Upper Duke Street and Hope Street
Cloud on Stanhope Street
Dog on Hope Street

amcewen, 2016-03-21:
Done!  And performed.

Closed 2016-03-21.

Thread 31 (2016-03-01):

Try out high intensity IR to communicate with the gondola instead of RF

goatchurchprime, 2016-03-01:
I'm getting a lot of unreliability with the jeenode RF communications now, once we took apart the old gondola.  Maybe the huge metal spanner in the works had been helping with reception.

Anyway, we can bet on this RF completely failing at the critical moment, and none of us will have enough clues about how to fix it.

I'd have more confidence with the IR comms tech outlined here: http://www.vishay.com/docs/80073/general.pdf
"""If we assume that the whole inner surface of a room (e.g. floor area of 30 m, height of 2.5 m) is irradiated with the emission of an infrared source with an overall irradiance of  e = 0.3 mW/m, then an emitted radiant flux of 35 mW is necessary (surface = 115 m, 100 % efficiency). With an 80 % reflection loss, about 175 mW of emitted radiation will be required for reliable reception in the whole room.

175 mW is a value, which can be achieved with an emitter TSAL6400 operating at a peak forward current of 500 mA. Under these conditions, no direct path between the emitter and the receiver is assumed, but that radiation will reach the detector after at least one reflection. This kind of remote control system is very user friendly for the customer because he can aim the handset in any direction of his living room. An IR emitter with a wide emitting angle will also provide this kind of comfortable remote control system"""

I feel that if we have high power narrower transmitting LEDs directed in range of the gondola whose IR detector is pointing in the right direction, then we will always be able to make it work.

There's some highly developed protocols here, which involve intense high frequency bursts on the IR LEDs to get more signal brightness out of them and increase their range.
    https://learn.sparkfun.com/tutorials/ir-communication

We should order the necessary items and program some 5V arduinos with enough power run stronger emitters and more sensitive detectors.

The comms need only be one-way, which definitely simplifies things.

DefProc, 2016-03-01:
Just a thought, but are you setting the right frequency to match the radio
modules? They are tuned to a single frequency by one of the external
components on the module.

While they will work at other frequencies, the range is greatly reduced.
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

amcewen, 2016-03-03:
As both this and issue #24 were suggestions for things to try to improve problems with the z-axis movement, I've edited issue #24 to describe the problem rather than a possible solution, and going to mark this one as a duplicate.

Future comments to go over there...

Closed 2016-03-03.

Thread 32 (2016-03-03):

Onshape Model

epsaul, 2016-03-03:
Have begun working up an Onshape public model for people to interogate/contribute to:
https://cad.onshape.com/documents/56d7184ce4b0f9d49ccaa29d/w/fd852f637eb1b9cffbe91a68/e/a35eaaea834af6a0bc05afee

DefProc, 2016-03-03:
I've just realised that there are some 2.4m long, 64mm wide, 12mm thick strips of ply in the storage room. They might give you those panel joining pieces.

epsaul, 2016-03-03:
Anyone who wants editing rights to the model, let me know your Onshape user details.
Thanks Patrick will check them out this evening if I get across.

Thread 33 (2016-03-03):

Design and build the drawing area for the main performance

amcewen, 2016-03-03:
Following the site visit (issue #19) we think it'll make most sense to hang a plywood screen off the scaffolding poles for the main performance polargraph.

For the main performance area - the projector screen can't easily be moved (and Lizzie has some photos she'd like to project onto it anyway).  We think the best approach is going to be to hang the drawing area to the left of the screen (when looking at it from the audience, like in https://www.flickr.com/photos/amcewen/24811058904/in/album-72157664813872800/).  There are hefty scaffold poles mounted vertically (as can be seen in https://www.flickr.com/photos/amcewen/25415458676/in/album-72157664813872800/ although those are to the right of the screen) which are 48mm diameter.  The ones to the left are 10 feet apart, so we could fairly easily hang a full size sheet of plywood between them.  We need to avoid the fire exit, but that's unlikely to be a problem.  The venue have the right kit to get access to them to do the hanging.  It's probably best to build it as a self-contained unit just needing power, as it'll be trickier (although not impossible) to have things on the floor below it (particularly on the left side, as that'll be off the edge of the stage and near the fire exit)

If we're doing that, (I think) it makes sense for the servo motors to be mounted directly to the screen, in which case we wouldn't need the second set of corner pulleys from issue #13, and the servo mounts in issue #3 would need to fasten onto the screen too.

amcewen, 2016-03-13:
This is being covered by the OnShape model in issue #32

Closed 2016-03-13.

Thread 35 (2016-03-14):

Right-hand stepper motor has stopped working

amcewen, 2016-03-14:
It was fine on Saturday, but when @epsaul and I were doing some testing yesterday, only the left-hand motor was working.

There seems to be power to it, and from a basic test with a multimeter it's getting steps and direction, so we're suspecting either the stepper driver board or the stepper motor itself.

amcewen, 2016-03-14:
It was the stepper driver board.  Swapping in another one has fixed matters.  (And I'll add another one to the list of things to buy #29)

Closed 2016-03-14.

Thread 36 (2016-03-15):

Laser-etch a credits file for Knut

amcewen, 2016-03-15:
It'd be nice to have a small board (A5-ish) to lean against the window that Knut is drawing on to explain a little what it is (or at least point people at where it was made).

Something along the lines of the DoES Liverpol logo, the name of the "Knut Polargraph" as a heading, and then the content of https://github.com/DoESLiverpool/Tosca/blob/master/Credits.md below

jackie1050, 2016-04-30:
Knut has been retired - open new issue to produce something similar for Liverpool MakeFest

Closed 2016-04-30.

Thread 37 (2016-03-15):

Glue the gondola wings onto their rings

amcewen, 2016-03-15:
The gondola wings (the bits that say "DoES" on them) could do with a drop of glue to hold them onto the rings.

amcewen, 2016-03-18:
Done for one of them, but not the other as we realised it would foul with the wooden section and you'd not be able to disassemble them at all.

Closed 2016-03-18.

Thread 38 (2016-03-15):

Set up FIO boards to do z-axis actuation

amcewen, 2016-03-15:
Now that we've switched to XBee for the wireless comms (see issue #24) we need to install the software onto the Arduino FIO boards we've ordered, and attach them to the gondolas.

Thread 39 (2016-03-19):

Investigate some non-contact drawing technology

goatchurchprime, 2016-03-19:
Pen on paper without any force applied seems to be an issue.

Apparently you can get very tiny lasers that can engrave.
   http://www.instructables.com/id/Pocket-laser-engraver/
We like lasers and they can be good for light night.  But they might be too slow (though worth a look at)

Alternatively there is paint spraying technology, which looks extremely good value for money:
    https://www.machinemart.co.uk/p/diy-air-brush-kit-cab1h/
    https://www.machinemart.co.uk/c/spray-guns-spraying-equipment-air-brushes/
You can get retractable hoses for the air supply, providing some pulldown
    https://www.machinemart.co.uk/p/clarke-9-metre-retractable-air-hose-reel-car/
(I can't find links to the air compressor product)

Can we find an artist who uses this tech already?  Paint stuff would be a mystery.  There might be some combination of paint substance and small laser curing to get the finer details.

jackie1050, 2016-04-25:
Airbrush, ink and propellant spray in my workshop box (should be moved to Tosca Polargraph box). Airbrush on indefinite loan so needs to be returned in same condition eventually. There seem to be cheap airbrush and compressor kits on eBay if this technology seems useful.

jackie1050, 2016-04-30:
Tried out airbrush on Thursday night - looks as though it will be good for writing as well as painting - need to look at line width etc. It worked well with a garden spray - Chris is going to bring in a fish tank pump to experiment with.

jamieisboss, 2016-05-13:
# **`etch-a-motherflipping-sketch`**

~~no clue how,~~

actually, i think i do, the gondola has a strong magnet , then corrugated plastic, I need to come back to this...

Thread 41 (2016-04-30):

Investigate portable drawing surface for use at performances away from DoES

jackie1050, 2016-04-30:
Needs to be large (around 2m x 2m), stable, have a smooth surface and allow attachment of polargraph mechanism and paper roll mechanism if used.

A folding exhibition stand (e.g. http://www.ebay.co.uk/itm/Fordable-Banner-Pop-Roll-Pull-up-Sign-Exhibition-Display-Stand-Show-W-PVC-Screen-/281317070231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) could be part of a potential solution, but needs further investigation.

jamieisboss, 2016-05-23:
As mentioned in #49 , I reckon a photographic backdrop holder with paper spool would be a good idea, remove the paper spool and add a metal bar and possibly an additional side piece for the middle and then aluminium foam-board seems to be all the rage for backgrounds at the moment, I've used it and it is pretty brill, lightweight but strong, you can print onto it, or paint/draw.

You can also get it in bare metal if you ever wanted to try electrocuting it to see if that left cool markings and wasn't horribly dangerous in an uncontrollable way (if you earthed the panel so the foam didn't come into play so much you might be able to draw with a Tesla coil, and change the tone(?) so it sang or sounded like  weird speech. I've got no experience or basis for thinking this beyond you tube and an A Level in physics that I got a D in, so not qualified to tell you to shoot electricity at things and bear no responsibility if anyone tries it without asking someone more knowledgeable first,

Just realised you could just use aluminium sheet  for the zapping, and the foam one for regular stuff.

jackie1050, 2016-05-29:
Ordered banner as detailed above - should be delivered 3 - 8 June (photographic backdrop holders look good but more expensive, so try this first)

jamieisboss, 2016-05-30:
If you end up wanting the backdrop holder, i had another idea that is probably a fair bit cheaper that would work similarly too so let me know if you end up wanting something else and i'll cost it up and show you .

What are you actually going to draw on with the display banner thing? Did you just get big paper and put it over the boards last time?

I'm interested and i might see if we can borrow/rent the Tosca from you for the freshers fair in september, they didn't approve all my grant to build what I wanted but renting something big and interactive for the two days should seem more financially sensible to them. Are you planniing on having a free control mode, like a joystick or something? I should probably read all the docs and todos!
ruh the day

jackie1050, 2016-06-21:
The folding exhibition screen works fine

Closed 2016-06-21.

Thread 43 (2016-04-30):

Investigate real-time controllers

jackie1050, 2016-04-30:
Look into controllers such as etch-a-sketch, typewriter or scribble pad that could allow people to send instructions straight to the polargraph without programming

jamieisboss, 2016-05-30:
i had a thought that this is kind of like a flight control system for a quadcopter, maybe there's something in that as the new controllers have a lot of intelligence and here are a few open source ones, i'l see if i can find anything later on

Thingomy, 2016-05-30:
I have some (theoretical) experience with generating gcode on an arduino -- it would be a simple matter to have a bunch of input devices (joystics, rotery encoders etc) connected to an arduino, and it output gcode to tosca. What kind of controller is tosca running? is it grbl or what?

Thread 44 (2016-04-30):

Design cabinet for motors and power supply

jackie1050, 2016-04-30:
For use in Dinky but as light and portable for other performances. Needs to allow access to switches, reset buttons etc. but not dangerous parts. Maybe polar bear themed.

DoESsean, 2016-05-03:
*For use in Dinky but as light and portable for other performances. Needs
to allow access to switches, reset buttons etc. but not dangerous parts.
Maybe polar bear themed.*

I appreciate that there is probably a reason for this, but I just love that
it sounds like the request of someone who is a bit obsessed with polar
bears, and is just trying to drop that in casually.

On Sat, Apr 30, 2016 at 2:56 PM, Jackie Pease <notifications@github.com>
wrote:

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

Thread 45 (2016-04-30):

Specify common interface for gondolas

jackie1050, 2016-04-30:
This should include the physical mechanism for attaching to wires e.g. hooks, communication e.g. XBees, and data to be sent, x-, y-, z-, a-, b-, c- axes, spindle speed etc. (what actually happens will vary depending on the gondola)

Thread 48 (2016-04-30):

Design new gondola for airbrush

jackie1050, 2016-04-30:

jackie1050, 2016-05-06:
Helicalbytes looking into pumps, airbrush standards

jamieisboss, 2016-05-23:
[I saw this and thought of this,](http://www.banggood.com/12V-DC-4L-or-Min-100PSI-High-Pressure-Diaphragm-Water-Pump-p-914447.html) what's the difference between an airbrush and a mist attachment on a hose? one of them has air in, and finer particles probably, so this isn't exactly the same but this could be useful of you were ever to do a really huge , side of a building type painting, if it shoots 4m it should mist a reasonable distance to get the paint to the wall , and for multi colour, you could just bolt a few of them together.

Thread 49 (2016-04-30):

Design a motorized dispenser for paper roll

jackie1050, 2016-04-30:
This could be attached to the top of the board

jamieisboss, 2016-05-22:
if you used [photographers background paper](http://www.wexphotographic.com/buy-tetenal-super-white-background-paper-roll-2-72-x-11m/p1538567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) it;s usualy heavy enough that you have to clamp it to stop  it unravelling,a really simple tapered plug or sprung out handles (like pogo pins) in one end should stop it from doing that if it's in rigght, then a cog and a gearmotor on the top pole he paper is sitting on should be simple enough.

That paper is pretty expensive, but it's huge and comes in hundreds of colours ad it's a preexisting use case there are [already systems you can buy](http://www.wexphotographic.com/buy-manfrotto-mn046mc-red-expan-with-red-metal-chain/p1011950) to control the roll(s) , i bet if i looked through that list there would be a remote control motorised one, Itd just be expensive and we can make one out of a bit of a bike and a pole.so bettter not to spend but nice to know [there are emergency options you could rent ](http://calumetrental.co.uk/background-support-kit)if something went pear shaped

jamieisboss, 2016-06-04:
I'll have a go at this if you want, do you have a link to the information about the paper roll you want to use? I'll work to that for weight and size.

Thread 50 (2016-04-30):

Investigate software for producing images in format polargraph can use

jackie1050, 2016-04-30:
e.g. Processing has libraries to render an image as dots of varying size and/or colour

jackie1050, 2016-10-18:
StippleGen (http://wiki.evilmadscientist.com/StippleGen, https://github.com/evil-mad/stipplegen ) is open source software which uses Voronoi diagrams to generate TSP paths and SVGs of dot images (Darren has been using it to produce laser cut stencils for clay tiles).
TSP paths could be very useful for producing images when Tosca's z-axis isn't working.
The source code is available on GitHub (Processing), so it might be possible to adapt it to calculate Voronoi regions with different shade numbers and use them for painting-by-numbers.

jamieisboss, 2017-07-16:
https://github.com/euphy/polargraphcontroller

jamieisboss, 2017-07-16:
https://github.com/euphy/polargraph_server_polarshield

jamieisboss, 2017-07-16:
https://github.com/cnc-club/gcodetools/blob/master/README.md

jamieisboss, 2017-07-16:
https://www.norwegiancreations.com/2015/08/an-intro-to-g-code-and-how-to-generate-it-using-inkscape/

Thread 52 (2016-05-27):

implement scuba tank solenoid control air brush technology

goatchurchprime, 2016-05-27:
The advantage here is it won't use a compressor and we should control the flow of air from the ground so we don't need an actuator on the gondola.  It just carries the pen with the button permanently held down.

If there is a delay between the valve and a pump of paint, this can be compensated in the toolpath of the3 G-code.

I've put a 3ltr 232 bar tank in the room with the machine tool with a 2-stage regulator (the one on the tank takes it down to 10bar, and the second one is breathable).  There's a second regulator I've taken to bits.  Also there are hoses that can be screwed into the ports.  (That means the hose has 140psi in it when you want 30psi)

Please note: all the diving equipment in the bag **is junk** (except the cylinder).  Please take it apart and reuse.  As a backup idea, if the air from the dismantled yellow regulator could go into the airbrush hose, and we could control the demand valve lever with a servo, then we'd be done.

There are notes of people running air brushes from scuba tanks:
http://www.britmodeller.com/forums/index.php?/topic/62088-airbrushing-with-a-scuba-tank/
http://www.scubaboard.com/community/threads/using-a-tank-to-power-an-airbrush.77105/

I can't find anything definitive.

Here are some notes of arduinos running solenoid valves
http://forum.arduino.cc/index.php?topic=133793.0
http://www.martyncurrey.com/controlling-a-solenoid-valve-from-an-arduino/

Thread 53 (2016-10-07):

Write instructions for new H-bridge direct voltage control system

goatchurchprime, 2016-10-07:
Servo motor drivers stripped out and Quadrature encoders wired directly into beaglebone, which has a new circuit board on it.

Machinekit and G-codes no longer the way forward.

This enables experimental feedback loops to be made, and a direct web interface systems.

goatchurchprime, 2016-10-07:
First you need to log on to the tosca machine.  This requires the IPnumber.

Make sure the ehternet cable is properly in and the green led is flickering

Look for an open SSH port by doing:
    nmap -p22 192.168.0.255/24
and try logging on to several until you get to machinekit

Alternatively, using scanning for the MAC address  84:eb:18:e3:61:f4
sudo arp-scan 192.168.0.0/24 | grep 84:eb

Log on using:

ssh machinekit@192.168.0.67
password: machinekit

goatchurchprime, 2016-10-07:
The IDE we are developing in can be reached at:
    http://192.168.0.67:3000/ide.html

The code we have is in /var/lib/cloud9

First thing you need to do is enable the 2 equp readers (must be su):

echo bone_eqep0 > /sys/devices/bone_capemgr*/slots
echo bone_eqep1 > /sys/devices/bone_capemgr*/slots

Then you can run the script that serves the position and controls the motors

python polar1.py

serving on ...

Now you can go to the webpage that connects to this script and controls the motors

http://192.168.0.67/static/polarplot.html

This file is in  /var/lib/cloud9/static (can be edited through the IDE)

goatchurchprime, 2016-10-07:
Code for the polar plot (server and webpage) is herehttps://github.com/DoESLiverpool/Tosca/tree/master/beaglehbridge

goatchurchprime, 2016-10-25:
Current instructions:

1) Turn on the left switch at the mains (the BB only)
http://192.168.0.67:3000/ide.html

2) Find the ip-number:
sudo arp-scan 192.168.0.0/24 | grep 84:eb
ssh machinekit@192.168.0.67
password: machinekit

3) Go to http://192.168.0.45:3000/ide.html
and using the shell command line window go to
    /var/lib/cloud9/bbhquad/polarcode

and run:
    /usr/local/opt/python-3.4.5/bin/python3.4 mainpolar.py

4) go to http://192.168.0.45/static/polarmotion.html
With the websocket connected, see how you can drag the yellow disk and have the red disk follow it

DefProc, 2016-11-07:
@goatchurchprime Seeing as you're talking feedback loops on stepper motors, have you seen: [Mechaduino](https://hackaday.io/project/11224-mechaduino) yet?

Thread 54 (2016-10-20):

Check and fix the H-bridge for left motor

goatchurchprime, 2016-10-20:
This is very underpowered.  So swap around motor to make sure it's the H-bridge.  If it is, then it's the cheap chinese one, which got melted anyway.  There are spares that could be soldered onto the board in place of it.

goatchurchprime, 2016-10-22:
got a young fellow to solder it during last makernight

Closed 2016-10-22.

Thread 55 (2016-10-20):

Make the point dragging demo use websockets

goatchurchprime, 2016-10-20:
Simple implementation available here:

https://websockets.readthedocs.io/en/stable/intro.html

Then have to commit the code here.

Other features:

(1) make better move PID control function

(2) Plot on page to scale and at the right orientation for the two motors

(3) Produce javascript loop that steps through and sends XY commands in realtime using:
      http://dmitrybaranovskiy.github.io/raphael/reference.html#Raphael.getPointAtLength
based on an SVG path sequence.
(this is a replacement for G-code.)

As there is feedback of the real position via the BB websocket, the progression along the path can speed up or slow down accordingly.  Thus implementing the proposed adaptive control in a very few lines of explicit code.  If we hang a weight onto the gondola it should respond immediately by going slower.

goatchurchprime, 2016-10-22:
nearly happening but for a problem getting eqeps to work under new os

goatchurchprime, 2016-10-25:
The dragging thing now works.  The code is at:
     https://bitbucket.org/goatchurch/bbhquad/src/4705c041c5b5df719388c7ff848c7d73ed17de3f/polarcode/?at=master

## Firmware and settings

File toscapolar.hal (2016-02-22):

# #######################################
#
# HAL file for BBB Cape with 3 servos
#
# Derived from example hm2-stepper config
#
# ########################################

# Launch the setup script to make sure hardware setup looks good
loadusr -w ./setup.sh


# ###################################
# Core EMC/HAL Loads
# ###################################

# kinematics
#loadrt trivkins
loadrt mk6skins 

# motion controller, get name and thread periods from ini file
loadrt tp
#loadrt [EMCMOT]EMCMOT servo_period_nsec=[EMCMOT]SERVO_PERIOD num_joints=[TRAJ]AXES
loadrt  [EMCMOT]EMCMOT servo_period_nsec=[EMCMOT]SERVO_PERIOD num_joints=[TRAJ]AXES tp=tp kins=mk6skins


# load low-level drivers
loadrt hal_bb_gpio output_pins=212,214,216 input_pins=211,213,215,217,219,221
# Vaild pins are 101-146 for P8, 201-246 for P9

loadrt [PRUCONF](DRIVER) prucode=$(LINUXCNC_HOME)/[PRUCONF](PRUBIN) [PRUCONF](CONFIG) halname=hpg
loadrt limit1 count=1

loadrt probe_parport

# ################################################
# THREADS
# ################################################

addf hpg.capture-position                 servo-thread
addf bb_gpio.read                         servo-thread
addf motion-command-handler               servo-thread
addf motion-controller                    servo-thread
addf limit1.0                             servo-thread
addf hpg.update                           servo-thread
addf bb_gpio.write                        servo-thread


# ######################################################
# Axis-of-motion Specific Configs (not the GUI)
# ######################################################


# ################
# X [0] Axis
# ################

# axis enable chain
newsig emcmot.00.enable bit
sets emcmot.00.enable FALSE
net emcmot.00.enable <= axis.0.amp-enable-out 
net emcmot.00.enable => hpg.stepgen.00.enable
net emcmot.00.enable => bb_gpio.p9.out-16
setp bb_gpio.p9.out-16.invert 1

# position command and feedback
net emcmot.00.pos-cmd <= axis.0.motor-pos-cmd
net emcmot.00.pos-cmd => hpg.stepgen.00.position-cmd

net motor.00.pos-fb <= hpg.stepgen.00.position-fb
net motor.00.pos-fb => axis.0.motor-pos-fb


# timing parameters
setp hpg.stepgen.00.dirsetup        [AXIS_0]DIRSETUP
setp hpg.stepgen.00.dirhold         [AXIS_0]DIRHOLD

setp hpg.stepgen.00.steplen         [AXIS_0]STEPLEN
setp hpg.stepgen.00.stepspace       [AXIS_0]STEPSPACE

setp hpg.stepgen.00.position-scale  [AXIS_0]SCALE

#setp hpg.stepgen.00.maxvel          [AXIS_0]STEPGEN_MAX_VEL
setp hpg.stepgen.00.maxaccel        [AXIS_0]STEPGEN_MAXACCEL

#setp hpg.stepgen.00.step_type       0
# P9.29 PRU1.out4
setp hpg.stepgen.00.steppin         143
# P9.31 PRU1.out2
setp hpg.stepgen.00.dirpin          142


# ################
# Y [1] Axis
# ################

# axis enable chain
newsig emcmot.01.enable bit
sets emcmot.01.enable FALSE

net emcmot.01.enable <= axis.1.amp-enable-out 
net emcmot.01.enable => hpg.stepgen.01.enable
net emcmot.01.enable => bb_gpio.p9.out-14
setp bb_gpio.p9.out-14.invert 1

# position command and feedback
net emcmot.01.pos-cmd <= axis.1.motor-pos-cmd
net emcmot.01.pos-cmd => hpg.stepgen.01.position-cmd

net motor.01.pos-fb <= hpg.stepgen.01.position-fb
net motor.01.pos-fb => axis.1.motor-pos-fb


# timing parameters
setp hpg.stepgen.01.dirsetup        [AXIS_1]DIRSETUP
setp hpg.stepgen.01.dirhold         [AXIS_1]DIRHOLD

setp hpg.stepgen.01.steplen         [AXIS_1]STEPLEN
setp hpg.stepgen.01.stepspace       [AXIS_1]STEPSPACE

setp hpg.stepgen.01.position-scale  [AXIS_1]SCALE

setp hpg.stepgen.01.maxvel          [AXIS_1]STEPGEN_MAX_VEL
setp hpg.stepgen.01.maxaccel        [AXIS_1]STEPGEN_MAXACCEL

#setp hpg.stepgen.01.step_type       0
# P9.30 PRU1.out5
setp hpg.stepgen.01.steppin         144
# P9.28 PRU1.out6
setp hpg.stepgen.01.dirpin          145


# ################
# Z [2] Axis
# ################

# axis enable chain
newsig emcmot.02.enable bit
sets emcmot.02.enable FALSE

net emcmot.02.enable <= axis.2.amp-enable-out 
net emcmot.02.enable => hpg.stepgen.02.enable
net emcmot.02.enable => bb_gpio.p9.out-12
setp bb_gpio.p9.out-12.invert 1

# position command and feedback
net emcmot.02.pos-cmd <= axis.2.motor-pos-cmd
net emcmot.02.pos-cmd => hpg.stepgen.02.position-cmd

net motor.02.pos-fb <= hpg.stepgen.02.position-fb
net motor.02.pos-fb => axis.2.motor-pos-fb


# timing parameters
setp hpg.stepgen.02.dirsetup        [AXIS_2]DIRSETUP
setp hpg.stepgen.02.dirhold         [AXIS_2]DIRHOLD

setp hpg.stepgen.02.steplen         [AXIS_2]STEPLEN
setp hpg.stepgen.02.stepspace       [AXIS_2]STEPSPACE

setp hpg.stepgen.02.position-scale  [AXIS_2]SCALE

#setp hpg.stepgen.02.maxvel          [AXIS_2]STEPGEN_MAX_VEL
setp hpg.stepgen.02.maxaccel        [AXIS_2]STEPGEN_MAXACCEL

#setp hpg.stepgen.02.step_type       0
# P9.26 PRU1.out8
setp hpg.stepgen.02.steppin         46
# P9.24 PRU1.out9
setp hpg.stepgen.02.dirpin          47



# ##################################################
# Standard I/O - EStop, Enables, Limit Switches, Etc
# ##################################################

# Probe
setp bb_gpio.p9.in-15.invert 1
net probe-in <= bb_gpio.p9.in-15
net probe-in => motion.probe-input

# Estop Signal 
net estop_loop bb_gpio.p9.in-11 => iocontrol.0.emc-enable-in
setp bb_gpio.p9.in-11.invert 1

# Stepper Enable
#net emcmot.00.enable => bb_gpio.p8.out-12

# create signals for tool loading loopback
net tool-prep-loop iocontrol.0.tool-prepare => iocontrol.0.tool-prepared
net tool-change-loop iocontrol.0.tool-change => iocontrol.0.tool-changed

# Machine power
# Use halui.machine.is-on instead?
#net emcmot.00.enable => bb_gpio.p9.out-12
#setp bb_gpio.p8.out-10.invert 1

#Cycle Start Button
#Should start the currently loaded program (for repeating parts)
#net halui.program.run <= bb_gpio.p8.in-09
#setp bb_gpio.p8.in-09.invert 1

#Spindle Start
#net spindle-fwd motion.spindle-forward => bb_gpio.p8.out-08



# ################
# Limit Switches
# ################

net all-home <= bb_gpio.p9.in-13
net all-home => axis.0.home-sw-in
net all-home => axis.1.home-sw-in
net all-home => axis.2.home-sw-in
 
#net limit-x-min <= bb_gpio.p9.in-23
#net limit-y-min <= bb_gpio.p9.in-25
#net limit-z-min <= bb_gpio.p9.in-27

# Adjust as needed for your switch polarity
setp bb_gpio.p9.in-13.invert 1
#setp bb_gpio.p9.in-25.invert 1
#setp bb_gpio.p9.in-27.invert 1

# Uncomment if you actually have limit switches setup
# You probably want to setup homing in the INI file, as well
#net limit-x-min => axis.0.home-sw-in
#net limit-y-min => axis.1.home-sw-in
#net limit-z-min => axis.2.home-sw-in

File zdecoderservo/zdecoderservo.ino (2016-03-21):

// this one plugs into the BeagleBone with P9.26 (Steppin02) to IRQ
// and P9.24 (dirpin02) to digital pin 5.

// integrates the position from the step and direction and 
// sends the word in the payload out to the RF

#include <Servo.h>

// Serial port used for logging
#define LOG Serial
//#include "SoftwareSerial.h"
//SoftwareSerial gLogSerial(10, 11); // RX, TX
//#define LOG gLogSerial

#ifdef LOG
#define P(X) LOG.print(X)
#define PH(X) LOG.print(X, HEX)
#else
#define P(X)
#define PH(X)
#endif

Servo penservo; 

int pinstep = 3; // irq1
int pindirection = 5;   // check PIND value below

int ledpin = 13; 
int actuatorpin = 6; 

int initialposition; 
bool binitialpositionset = false; 

long servolo = 20; 
long servohi = 160; 

long zlo = -100; 
long zhi = 10; 

void initialcycle(bool bshowactuate) 
{
    // initial flow through two cycles to see it move
    for (int i = 0; i < 2; i++) {
        P("actuate "); 
        P(i); 
        P("\r\n"); 
        for (int j = 50; j <= 200; j++) {
            if (bshowactuate)
                penservo.write(map(j, 50, 200, servolo, servohi)); 
            delay(5); 
            digitalWrite(ledpin, (((j/10) % 2) == 1 ? HIGH : LOW)); 
        }
        for (int j = 200; j >= 50; j--) {
            if (bshowactuate)
                penservo.write(map(j, 50, 200, servolo, servohi)); 
            delay(5); 
            digitalWrite(ledpin, (((j/10) % 2) == 1 ? HIGH : LOW)); 
        }
    }
    binitialpositionset = false; 
}

void setup() 
{
#ifdef LOG
    LOG.begin(9600);
#endif
    P("Hello world\r\n");
    pinMode(pinstep, INPUT); 
    pinMode(pindirection, INPUT); 
    attachInterrupt(1, incz, RISING);
    P("Let's go!\r\n");
    pinMode(ledpin, OUTPUT); 

    penservo.attach(actuatorpin); 
    
    //while (true) 
    delay(1000);
    initialcycle(true); 
}

volatile int zpos = 0; 
void incz() 
{
    if (PIND & 0x20)  // pindirection==5!
        zpos++; 
    else
        zpos--; 
}

int prevzpos; 
int ncount = 0; 
long npingcount = 1000; 
int ledtoggle; 

void loop() 
{
    digitalWrite(ledpin, ((++ledtoggle) % 2 ? HIGH : LOW)); 
    int servopos = map(constrain(zpos, zlo, zhi), zlo, zhi, servolo, servohi); 
    penservo.write(servopos); 
#if 0
    P("\r\nZ");
    P(zpos);
    P(" S");
    P(servopos);
#endif
    delay(20);
}

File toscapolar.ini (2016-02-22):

# Generated by stepconf at Sat Mar 16 14:56:11 2002
# If you make changes to this file, they will be
# overwritten when you run stepconf again

[PRUCONF]
DRIVER=hal_pru_generic
CONFIG=pru=1 num_stepgens=3 num_pwmgens=0
PRUBIN=rtlib/xenomai/pru_generic.bin

[EMC]
MACHINE = mk7
DEBUG = 0

[DISPLAY]
DISPLAY = axis
EDITOR = gedit
POSITION_OFFSET = RELATIVE
POSITION_FEEDBACK = ACTUAL
MAX_FEED_OVERRIDE = 1.2
INTRO_GRAPHIC = linuxcnc.gif
INTRO_TIME = 5
PROGRAM_PREFIX = /home/ag/linuxcnc/nc_files
INCREMENTS = 5mm 1mm .5mm .1mm .05mm .01mm .005mm
#OPEN_FILE = /home/andy/emc2/nc_files/offsetg54.ngc
# all following are jog speeds
#DEFAULT_LINEAR_VELOCITY = .04
#MAX_LINEAR_VELOCITY = 50
#MIN_LINEAR_VELOCITY = .03

[FILTER]
PROGRAM_EXTENSION = .png,.gif,.jpg Greyscale Depth Image
PROGRAM_EXTENSION = .py Python Script
png = image-to-gcode
gif = image-to-gcode
jpg = image-to-gcode
py = python

[TASK]
TASK = milltask
CYCLE_TIME = 0.010

[RS274NGC]
PARAMETER_FILE = pru-stepper.var

[EMCMOT]
EMCMOT = motmod
COMM_TIMEOUT = 1.0
COMM_WAIT = 0.010
BASE_PERIOD = 35900
SERVO_PERIOD = 1000000

[HAL]
HALFILE = toscapolar.hal
HALFILE = custom.hal
POSTGUI_HALFILE = custom_postgui.hal

[TRAJ]
AXES = 3
COORDINATES = X Y Z
LINEAR_UNITS = mm
ANGULAR_UNITS = degree
CYCLE_TIME = 0.010
DEFAULT_VELOCITY = 100.00
#max vel of machine with slider control
MAX_LINEAR_VELOCITY = 140.00

[EMCIO]
EMCIO = io
CYCLE_TIME = 0.100
TOOL_TABLE = tool.tbl

[AXIS_0]
TYPE = LINEAR
##final move
HOME = 0
MAX_VELOCITY = 2000
STEPGEN_MAX_VEL = 2500
MAX_ACCELERATION = 3000.0
STEPGEN_MAXACCEL = 3300.0
SCALE = 42
FERROR = 1
MIN_FERROR = 0.25
#tbl screw min length 170 but x min is....
MIN_LIMIT = -600
MAX_LIMIT = 620
HOME_OFFSET = 0
HOME_SEARCH_VEL = 0
HOME_LATCH_VEL = 0
HOME_FINAL_VEL = 0
##USE_INDEX = NO
HOME_SEQUENCE = 2 
DIRSETUP = 5000
DIRHOLD = 5000
STEPLEN = 1500
STEPSPACE = 500

[AXIS_1]
TYPE = LINEAR
##final move
HOME = 0
MAX_VELOCITY = 2000.0
STEPGEN_MAX_VEL = 2500
MAX_ACCELERATION = 3000.0
STEPGEN_MAXACCEL = 3300.0
SCALE = 42
FERROR = 1
MIN_FERROR = 0.25
MIN_LIMIT = -600 
MAX_LIMIT = 600
HOME_OFFSET = 0
HOME_SEARCH_VEL = 0
HOME_LATCH_VEL = 0
HOME_FINAL_VEL = 0
HOME_SEQUENCE = 1
DIRSETUP = 5000
DIRHOLD = 5000
STEPLEN = 1500
STEPSPACE = 500

[AXIS_2]
##final move (not connected anyway)
HOME = 0
MAX_VELOCITY = 3300
MAX_ACCELERATION = 300.0
STEPGEN_MAXACCEL = 375.0
STEPGEN_MAX_VEL = 4400
SCALE = 800.0
FERROR = 1
MIN_FERROR = 0.25
MIN_LIMIT = -1.0
MAX_LIMIT = 90.0
##limit switch
HOME_OFFSET = 0
HOME_SEARCH_VEL = 0
HOME_LATCH_VEL = 0
HOME_FINAL_VEL = 0
#USE_INDEX = NO
HOME_SEQUENCE = 0
DIRSETUP = 5000
DIRHOLD = 5000
STEPLEN = 1500
STEPSPACE = 500

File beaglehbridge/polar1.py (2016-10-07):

from mmap import mmap
import time, struct, sys, ctypes, select, threading, socket, re, atexit
from Adafruit_BBIO import PWM
from Adafruit_BBIO import GPIO

print("hi there", __name__)

portnumber = 9019
qdistcutoff = 2000

# load the capes for the eqeps using:
# echo bone_eqep0 > /sys/devices/bone_capemgr*/slots
# echo bone_eqep1 > /sys/devices/bone_capemgr*/slots


arm = "P9_12"
pwm0 = "P9_16"
pwm1 = "P9_21"
pwm2 = "P9_14"


PWMSS0_offset = 0x48300000
PWMSS0_size = 0x4830025F - PWMSS0_offset + 1
PWMSS1_offset = 0x48302000
PWMSS1_size = 0x4830225F - PWMSS1_offset + 1
PWMSS2_offset = 0x48304000
PWMSS2_size = 0x4830425F - PWMSS2_offset + 1

fp = open("/dev/mem", "r+b" )
memp0 = mmap(fp.fileno(), PWMSS0_size, offset=PWMSS0_offset)
memp1 = mmap(fp.fileno(), PWMSS1_size, offset=PWMSS1_offset)
#memp2 = mmap(fp.fileno(), PWMSS2_size, offset=PWMSS2_offset)
QPOSCNT = 0x180 + 0x00
QCAPCTL = 0x180 + 0x2C
memp0[QCAPCTL:QCAPCTL+4] = struct.pack("<L", 0x8000)
memp1[QCAPCTL:QCAPCTL+4] = struct.pack("<L", 0x8000)
#memp2[QCAPCTL:QCAPCTL+4] = struct.pack("<L", 0x8000)

class PolarAxis:
    def __init__(self, memp, pwm):
        self.memp = memp
        self.pwm = pwm
        self.qpos = 0
        self.qstart = None
        self.qdestination = None
        self.qsumerror = 0
        self.qvolts = 0
        self.dc = 0
        
    def readeqep(self):
        self.qpos = struct.unpack("<l", self.memp[QPOSCNT:QPOSCNT+4])[0]
        if self.qstart is None:
            self.qstart = self.qpos
            self.qdestination = self.qpos

    def updatevolts(self, dt):
        if self.qdestination is None:
            self.qvolts = 50
            return
        d = self.qdestination - self.qpos
        if abs(d) > 900:
            self.qsumerror = 0
        else:
            self.qsumerror += d*dt*0.001
            self.qvolts = -d*0.01 - self.qsumerror*6
            
    def updateduty(self, t0):
        modpunch = int(t0*200) % 8
        bpunch = (modpunch <= 0) if abs(self.qvolts) > 3.1 else (modpunch <= 2)
        fac = 3 if bpunch else 1
        bnds = 25 if bpunch else 15
        dc = max(-bnds, min(bnds, self.qvolts*fac))
        self.dc = dc+50
        PWM.set_duty_cycle(self.pwm, dc+50)

class PolarPos:
    def __init__(self, arm, axes):
        self.arm = arm
        self.polaraxes = [ PolarAxis(memp, pwm)  for memp, pwm in axes ]
        self.updatedutycount = 0
        self.t0 = time.time()
        
        if self.arm:
            GPIO.setup(self.arm, GPIO.OUT)
            GPIO.output(self.arm, GPIO.LOW)
        for memp, pwm in axes:
            if pwm:
                print("starting", pwm)
                PWM.start(pwm, 50, 100000, 1)
        if self.arm:
            GPIO.output(self.arm, GPIO.HIGH)

        def settostationary(armaxes):
            arm, axes = armaxes
            if arm:
                GPIO.output(arm, GPIO.LOW)
            for memp, pwm in axes:
                print("set stationary", pwm, arm)
                if pwm:
                    PWM.start(pwm, 50, 100000, 1)
        atexit.register(settostationary, (arm, axes))  # values kept here by closure
        self.readeqeps()

    def readeqeps(self):    
        for pa in self.polaraxes:
            pa.readeqep()

    def updateduty(self):
        self.updatedutycount += 1
        t1 = time.time()
        dt = t1 - self.t0
        self.t0 = t1
        for pa in self.polaraxes:
            pa.updatevolts(dt)
            pa.updateduty(t1)


stdincommand = 'c'
def readstdin():
    global stdincommand
    while True:
        c = sys.stdin.read(1)
        if c == 'q':
            stdincommand  = c

input_thread = threading.Thread(target=readstdin)
input_thread.setDaemon(True)
input_thread.start()

def readhttp(polarpos):
    global ccommand, qp
    
    # find the ip address we are working from
    s = socket.socket(socket.AF_INET, socket.SOCK_DGRAM)
    s.connect(("8.8.8.8", 80))
    ipaddress = s.getsockname()[0]
    
    # now make the connection
    print("serving on %s:%s" % (ipaddress, portnumber))
    s = socket.socket(socket.AF_INET, socket.SOCK_STREAM)
    s.bind((ipaddress, portnumber))
    s.listen(1)
    connectioncount = 0
    
    while True:
        connectioncount += 1
        #print("waiting for connection", connectioncount)
        conn, address = s.accept()
        buf = conn.recv(1024)
        #print("received ", len(buf), buf)
        posvals = ",".join(str(pa.qpos)  for pa in polarpos.polaraxes)
        data = "pos(%s,%d);\n" % (posvals, polarpos.updatedutycount)
        
        mxy = re.match("GET /x([0-9\-\.]+)y([0-9\-\.]+)", buf)
        if mxy:
            if len(polarpos.polaraxes) >= 1:
                polarpos.polaraxes[0].qdestination = int(mxy.group(1))
            if len(polarpos.polaraxes) >= 2:
                polarpos.polaraxes[1].qdestination = int(mxy.group(2))
            print("goingto", [pa.qdestination for pa in polarpos.polaraxes])

        
        conn.send('HTTP/1.0 200 OK\r\n')
        conn.send('Connection: close\r\n')
        conn.send('Content-Length: %d\r\n' % len(data))
        conn.send('Content-Type: text/html\r\n')
        conn.send('\r\n')
        try:
            conn.send(data)
            conn.close()
        except:
            pass
        

if __name__ == "__main__":
    polarpos = PolarPos(arm, [(memp1, pwm0), (memp0, pwm1)])
    http_thread = threading.Thread(target=readhttp, args=(polarpos,))
    http_thread.setDaemon(True)
    http_thread.start()
    
    tS = time.time()
    
    while True:
        polarpos.readeqeps()
        if max(abs(pa.qpos-pa.qstart)  for pa in polarpos.polaraxes) > qdistcutoff:
            print("too far shutting down")
            break
        
        polarpos.updateduty()
        ltS = time.time()
        if ltS - tS > 1:
            tS = ltS
            print([pa.qpos for pa in polarpos.polaraxes], [pa.qdestination for pa in polarpos.polaraxes], ["%.3f"%pa.qvolts for pa in polarpos.polaraxes], ["%.3f"%pa.qsumerror for pa in polarpos.polaraxes], ["%.3f"%pa.dc for pa in polarpos.polaraxes])
        if stdincommand == 'q':
            sys.exit(0)

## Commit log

2016-02-17 Add initial notes from trying to get the Beaglebone working with the stepper motors. Part of issue #1
2016-02-20 Add the Beaglebone pinouts link to the Machinekit instructions. Tidy up stepper notes.
2016-02-22 Add hal and ini files
    [toscapolar.hal]
2016-02-25 Add jeenode code that transmits the z codes to the actuator jeenode on the gondola
2016-02-28 Make variable used in ISR volatile.
    Should help with #24. Variables used both in interrupt routines and the main code need to be volatile so that the compiler makes sure to load it from memory after each access (rather than assume some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
2016-03-13 Rework Z-axis sketches to use XBee rather than RF12. Part of #24
    [jeenodezdecoder.ino]
2016-03-14 Servo Pully
    The STL and Solidworks files for a servo pully.
    [servo pully.SLDPRT, servo pully.STL]
2016-03-15 Update code to fix deployment on Jeenode (and stop the logging from interfering with the servo!). Part of #24
2016-03-17 Updating addresses for new whip-antenna XBee modules
2016-03-17 Updates for new whip-antenna XBee modules
2016-03-21 Add non-wireless z-axis code.
